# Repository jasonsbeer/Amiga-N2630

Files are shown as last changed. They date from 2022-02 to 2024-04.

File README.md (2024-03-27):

  
The N2630 is a 50MHz Motorolla MC68030 CPU card with additional RAM and ATA device port for the Amiga 2000 family of computers. It is installed in the CPU slot where it immediately upgrades the system to the MC68030 processor with FPU, up to 264 megabytes of Fast RAM, and an ATA port. The N2630 is intended to be an evolution of the A2630 card.  

<br />Look for the N2630 channel on Discord: https://discord.gg/NU7SPYfNFj  

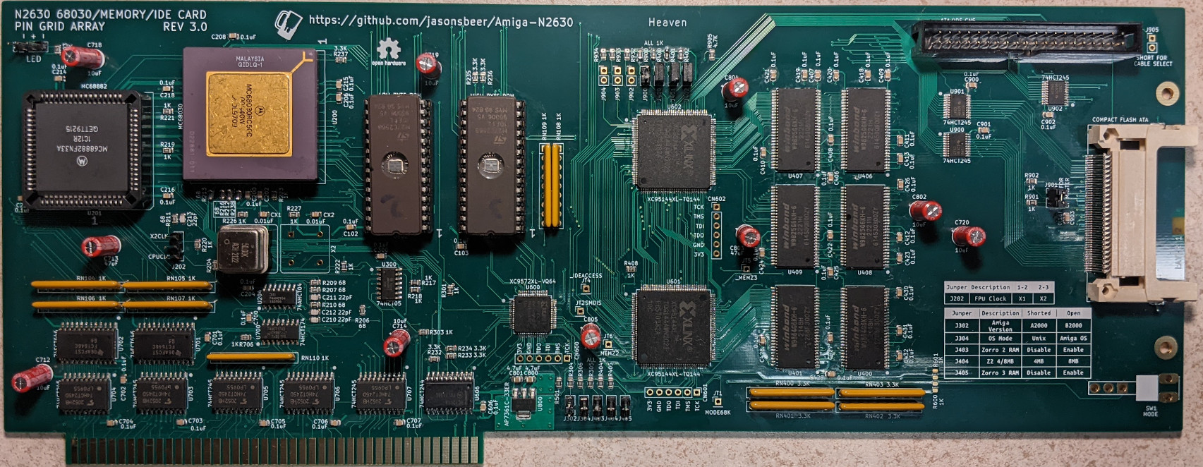
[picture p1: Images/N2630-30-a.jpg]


## CURRENT STATUS:
**Revision 4.1.0a/b is the current production release.**  

Sub-revision "a" supports the PLCC footprint MC68882. Sub-revision "b" supports the PGA footprint MC68882. They are otherwise identical.  

See the [issues](https://github.com/jasonsbeer/Amiga-N2630/issues) tab for known issues. [Click here](/TestedDevices.md) to see a list of devices tested with the N2630.

<p align="center">
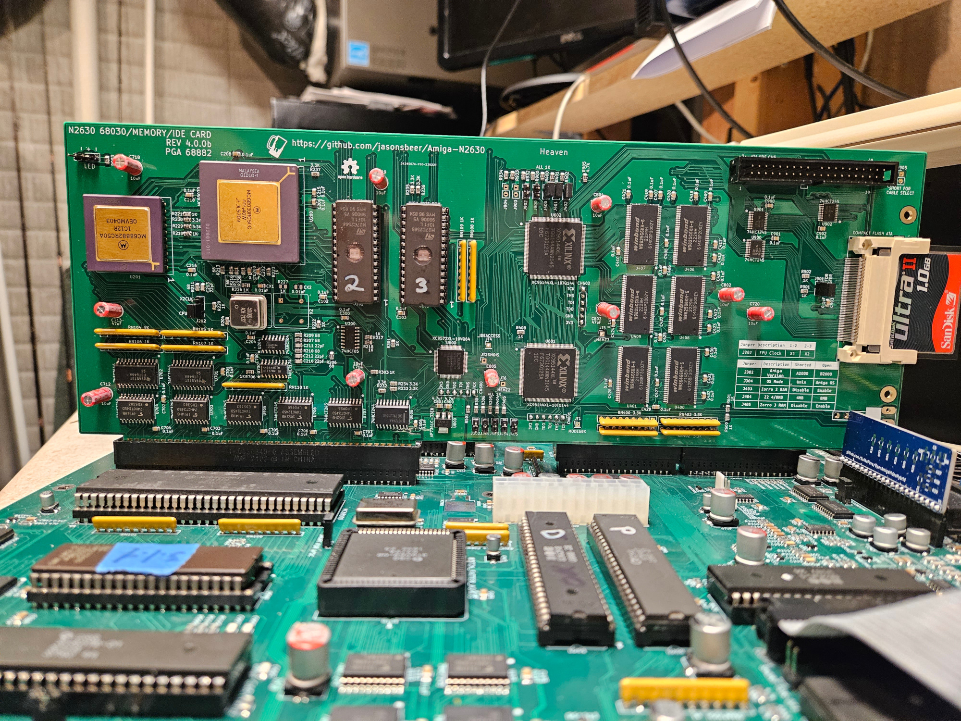
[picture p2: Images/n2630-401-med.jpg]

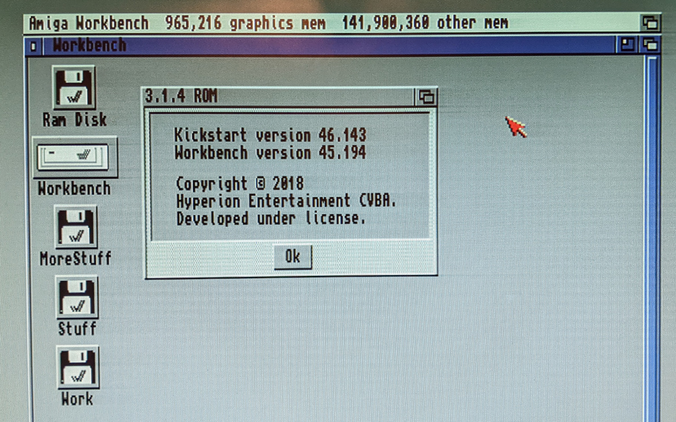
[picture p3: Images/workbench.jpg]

</p>

## Features
1. Motorola 68030 microprocessor running at 50MHz.
2. Motorola 68882 math coprocessor running up to 50MHz.
3. 4 or 8 megabytes of Zorro 2 Fast RAM.
4. 16 to 256 megabytes of Zorro 3 Fast RAM.
5. ATA port with 40-pin cable and compact flash card options.

## Assembly Notes
Click [here](/AssemblyNotes.md) for more information on building the N2630.

## Installation Notes
This card may be installed in any Amiga 2000 computer. Installation is simply inserting the card into the 86 pin CPU/Coprocessor slot of the Amiga computer. There are no software drivers to install.  Kickstart v37.300 and greater is recommended.

**IMPORTANT:** Before installing a Revision 4.x.x or greater N2630, it is necessary to determine if you have an early, non-cost reduced motherboard. If your motherboard is marked "Made In Germany" and "(C) 1986 Commodore" on the left side of the board, you have a non-cost reduced Amiga 2000 board, designated "A2000" in this documentation. An example of a non-cost reduced Amiga 2000 motherboard can be see [here](http://amiga.resource.cx/photos/a2000,1). In the event you have an non-cost reduced "A2000" motherboard, you must remove the Motorola 68000 processor from the Amiga 2000 motherboard and place a jumper at J302 of the N2630.  All other Amiga 2000 motherboards are designated "B2000" and should leave the Motorola 68000 in place. Revision 3.0.x cards do not support the original German A2000. 

**NOTES:**  
**1) Hardware revision 4.x.x supports the original Germal A2000, but is untested.**  
**2) The A2091 hard drive card will not operate correctly when using Kickstart 1.x on a revision 6.2 or newer Amiga 2000 with the N2630 or A2630 CPU cards. You must use Kickstart 2.04 or newer.**

## 68030 Mode
By default, the N2630 starts in 68030 mode. When in 68030 mode, all installed RAM and the ATA device port are active.

## 68000 Mode
When desired, the 68030 may be disabled during a cold or warm start. This results in the Amiga falling back to the 68000 processor. This may be desired when software does not run correctly on the 68030 processor. To start up in 68000 mode, hold down the right mouse button during startup. Select "68000" and the Amiga will reset with the 68000 as the active processor. When in 68000 mode, the ATA port and on-board RAM are inactive. Motorola 68000 mode is not available with A2000 motherboards.

## 68882 Math Coprocessor (FPU)
The Motorolla MC68882 (or MC68881) floating point unit may be optionally added to the N2630. The FPU is typically driven at the same clock frequency as the MC68030 via the X1 oscillator, but may be clocked independently via the X2 oscillator (see Table 3, J202).

## ROMs
The N2630 requires two 27C256 EPROMs (burned by the user) to function. The ROMs handle the system startup for CPU selection and contains the [LIDE.device](https://github.com/LIV2/lide.device) AUTOBOOT ROM. See the instructions [here](/ROMs.md) for burning the N2630 ROMs.

## FAST RAM
The N2630 uses SDRAM to provide the necessary memory for the Amiga system. SDRAM is the successor to Fast Page Memory found in devices such as the Amiga 3000, A2630 processor card, and other computers of the time. SDRAMs are a cost effective way to supply memory to older systems and are readily available either new or from unused memory modules. 

### Zorro 2
Zorro 2 RAM is the Amiga RAM found in the 24 bit address space of the Motorola MC68000 processor. The Zorro 2 RAM on the N2630 is accessed by the 68030 as a 32-bit data bus and supports 16-bit DMA activities of the Zorro 2 bus. Placing a jumper at position J404 will limit the amount of RAM to 4MB in the Zorro 2 space, allowing 4MB of address space to be made available to other Zorro 2 devices. As an example, if you have a 4MB Zorro 2 video card, it will be necessary to set jumper J404 to free up this address space for the video card. Failure to do so will result in the video card failing to pass the AUTOCONFIG process. As another example, if you have two 4MB Zorro 2 devices, such as a video card and Bridge card, these devices require the entire 8MB Zorro 2 address space. In this situation, you must disable the Zorro 2 RAM entirely by placing a jumper at J403.

Using expansion memory on the Zorro 2 bus is not recommended, as this will negatively impact the performance of the MC68030 when accessing this memory on the Zorro 2 bus. The expansion memory on the N2630 should always be used as a first choice.

NOTE: Any SDRAM at least 2Mx16 in capacity in the 54-TSOP II footprint may be placed. However, it is not possible to achieve more than 8 megabytes of Zorro 2 RAM capacity. 

### Zorro 3
Zorro 3 RAM is the Amiga RAM found in the 32-bit address space of the Motorola MC68030 processor. The Zorro 3 RAM on the N2630 supports the cache burst mode of the 68030 processor. Both Zorro 2 and Zorro 3 RAM are used together on the N2630 card. Thus, the total memory available to the system will be the sum of the Zorro 2 and Zorro 3 RAM. 

Zorro 3 SDRAMs may be installed in different configurations to achieve a specific amount of final RAM (Table 1a). SDRAM must be installed in pairs, or banks, to achieve the needed 32 bit data path. Positions U406 and U407 represent the "low" bank and positions U408 and U409 represent the "high" bank. The banks must be populated as the low bank only or both low and high banks. The high bank will not function without the low bank populated. The SDRAM footprint is 54-TSOP II. The indicated jumpers must be set as shown or your system may not function correctly. When installing both banks, jumpers J400 and J401 must be set as shown in tables 1b and 1c. If only the low bank is populated, these jumpers are not used.

The Zorro 3 memory supports AUTOCONFIG with Kickstart 2.04 and newer and will be auto sized by Amiga OS. When using Kickstart version 1.x, place a jumper at J405 to disable the Zorro 3 AUTOCONFIG. An addmem style program may be used to add the Zorro 3 memory to the Amiga's memory pool. See Table 1d for the N2630 Zorro 3 memory map.

**Table 1a.** Possible Zorro 3 RAM Combinations for the N2630.
Desired Zorro</br>3 RAM (MB)|SDRAM|Low Bank</br>(U406 and U407)|High Bank</br>(U408 and U409)
-|-|-|-
16|4MX16|Populated<sup>A</sup>|Unpopulated<sup>B</sup>
32|4MX16|Populated|Populated
32|8MX16|Populated|Unpopulated
64|8MX16|Populated|Populated
64|16MX16|Populated|Unpopulated
128|16Mx16|Populated|Populated
128|32MX16|Populated|Unpopulated
256|32MX16|Populated|Populated

<sup>A</sup>These SDRAM positions are populated by the SDRAM indicated.  
<sup>B</sup>This SDRAM positions are not populated.

**Table 1b.** SDRAM Bank Jumper Setting.
Zorro 3 RAM</br>Banks Populated|J400
-|-
Low Bank Only|Open<sup>A</sup>
Both Banks|Shorted<sup>B</sup>

<sup>A</sup>No jumper.  
<sup>B</sup>Jumper placed. 
  
**Table 1c.** Jumper Configurations When Both Low and High Memory Banks Are Populated.
Desired Zorro</br>3 RAM (MB)|SDRAM</br>Capacity|J401<sup>[A]</sup>|J402<sup>[A]</sup>
-|-|-|-
32|4MX16|Open<sup>[B]</sup>|Shorted<sup>[C]</sup>
64|8MX16|Shorted|Open
128|16Mx16|Shorted|Shorted
256|32MX16|Open|Open

<sup>A</sup>Ignored when J400 is open.  
<sup>B</sup>No jumper.  
<sup>C</sup>Jumper placed.  

**Table 1d.** N2630 Zorro 3 Memory Map.
Desired Zorro</br>3 RAM (MB)|Starting Address|Ending Address
-|-|-
16|$40000000|$40FFFFFF
32|$40000000|$41FFFFFF
64|$40000000|$43FFFFFF
128|$40000000|$47FFFFFF
256|$40000000|$4FFFFFFF

## ATA Port
The N2630 includes a buffered, host terminated AUTOBOOT ATA port for hard drives and ATAPI devices. The N2630 implements [LIDE.device](https://github.com/LIV2/lide.device) as the ATA driver. The driver must be present on the N2630 ROMs for the ATA port to function. See [ROMs](#roms) for more details. The ATA port may be accessed via the 40-pin ATA header and the compact flash card slot. There are a few different ways to combine devices on the port, but the total number of ATA devices on the N2630 cannot exceed two (master and slave). For instructions on installing a new hard drive on Amiga computers, refer to the [Commodore Hard Drive User's Guide](DataSheet/Hard_Drive_Users_Guide.pdf). This includes the HDToolBox user guide and other useful information for setting up both ATA and SCSI devices. 

The ATA logic supports four speed modes: PIO0, PIO2, PIO4, and SanDisk Ultra 2 (see Table 2B). The modes PIO0, PIO2, and PIO4 follow the published timing specifications of those modes, with PIO0 being the slowest. The SanDisk Ultra 2 mode was developed for the SanDisk Ultra 2 compact flash card and is capable of 7.4M/s transfer rate. The SanDisk Ultra 2 mode is an undocumented ATA timing and may or may not work with other devices. The speed mode you select will be determined by the slowest ATA device on your system. To determine what speed your devices support, it is recommended to start with the slowest setting (PIO0) and adjust one setting faster until one of your devices stops working. The mode you choose should be the fastest mode where all devices function correctly. Jumpers should only be changed while the system is off.

Each ATA device must be set as slave or master. Devices present on the 40 pin ATA port may use cable select by shorting J905 when using a proper cable select ATA cable. See the manual for each device on how to designate the device's master or slave setting. Master and slave for the compact flash device are set via J901 on the N2630.

**NOTE:** The compact flash card slot is not affected by the cable select jumper (J905).  Thus, J905 should only be used when a proper cable select ATA cable is implemented on the 40 pin ATA port.

**Table 2A.** ATA Configuration Jumper Settings.
Jumper|Description|Open<sup>[A]</sup>|Shorted<sup>[B]</sup>
-|-|-|-
J900|RESERVED||
J901|Compact Flash Select|Slave|Master
J902|PIO MODE||
J903|PIO MODE||
J904|RESERVED||
J905|Cable Select|Disable|Enable

<sup>A</sup>No jumper.  
<sup>B</sup>Jumper placed. 

**Table 2B.** ATA PIO Mode.
Mode|J902|J903
-|-|-
PIO0|Shorted<sup>[A]</sup>|Shorted|
PIO2|Shorted|Open<sup>[B]</sup>|
PIO4|Open|Shorted|
SanDisk Ultra 2|Open|Open|

<sup>A</sup>Jumper placed.  
<sup>B</sup>No jumper.  

## Other Jumper Settings
In the following tables, OPEN indicates no jumper. Shorted indicates the presence of a jumper on the pins indicated. All jumpers must be set correctly or you may encounter unexpected behaviors or failure to boot.

**Table 3a.** Configuration Jumper Settings
Jumper|Description|Shorted|Open<sup>[A]</sup>
-|-|-|-
J302|Amiga Version|A2000|B2000
J304|OS Mode|Unix|Amiga OS
J403|Zorro 2 RAM|Disable|Enable
J404|Z2 4/8MB|4MB|8MB
J405|Zorro 3 RAM|Disable|Enable

<sup>A</sup>The factory configuration for all jumpers is open (no jumper).  

**Table 3b.** System Clock Jumper Settings
Jumper|Description|1-2|2-3
-|-|-|-
J202|FPU Clock|X1<sup>[A]</sup>|X2<sup>[B]</sup>

<sup>A</sup>FPU clock from X1. Factory default.  
<sup>B</sup>FPU clock from X2.

## Revision History
<strong>Revision 4.1.0a/b</strong>  
   Added ATA activity light buffer to address config issues with some ATA devices.  
   Changed polarity of the ATA LED header.  
   
<strong>Revision 4.0.1a/b</strong>  
   Sub-revision 'a' supports PLCC MC68882, sub-revision 'b' supports the PGA MC68882.  
   Changed jumper footprint to increase ease of assembly.  
   Added order number location for JLCPCB.  
   Added support for original German A2000 machines.
   
<strong>Revision 3.0.1</strong>  
   Added copper thieving areas to top and bottom layers.  
   
<strong>Revision 3.0</strong>  
   Initial production release.  

## Acknowledgements
Dave Haynie for sharing the A2630 technical details with the Amiga community.  
Matt Harlum (LIV2) for sharing his Gayle ATA code, LIDE.device, submitting code improvements, listening my struggles, and his numerous other contributions to this project.  
Stephen Durham (steveed) for loaning me his ethernet cards.  
Members of the Discord testing group: LIV2, steeveed, Chrissy, Pillock.  
Everyone who made the Amiga possible.  

Last Updated: March 26, 2024

## License
<br />This work is licensed under a <a rel="license" href="http://creativecommons.org/licenses/by-nc-sa/4.0/">Creative Commons Attribution-NonCommercial-ShareAlike 4.0 International License</a>.

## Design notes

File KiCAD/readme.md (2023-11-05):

These are KiCAD files for the N2630.  

There are two versions of the N2630 card. One for the PLCC footprint MC68882 coprocessor and one for the PGA footprint MC68882 coprocessor. The two sub-revisions are otherwise identical.

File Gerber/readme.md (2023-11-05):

These are Gerber files for the Rev 4.0.1 N2630.  

There are two versions of the N2630 card. One for the PLCC footprint MC68882 coprocessor and one for the PGA footprint MC68882 coprocessor. The two sub-revisions are otherwise identical. Choose the one that best meets your needs.

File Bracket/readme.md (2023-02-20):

These are mounting brackets for the N2630. All files are included to 3D print or edit the brackets. There is one for the Commodore Amiga 2000 and one for the A2000 EATX.

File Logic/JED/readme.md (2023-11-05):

These are the current production JED files for programming the Xilinx CPLDs.

The U600 "SE" logic replaces the E clock CIA timing in favor of timings from the 8520A datasheet. This is the preferred logic for most applications. If you have a Zorro 2 device that relies on E clock timings, you should use the non-SE logic version for U600.

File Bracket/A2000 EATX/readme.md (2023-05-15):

Mounting bracket for the N2630 and Amiga 2000 EATX computer. Designed to use M3x5 or similar sized screws. STL and FreeCAD files are included.

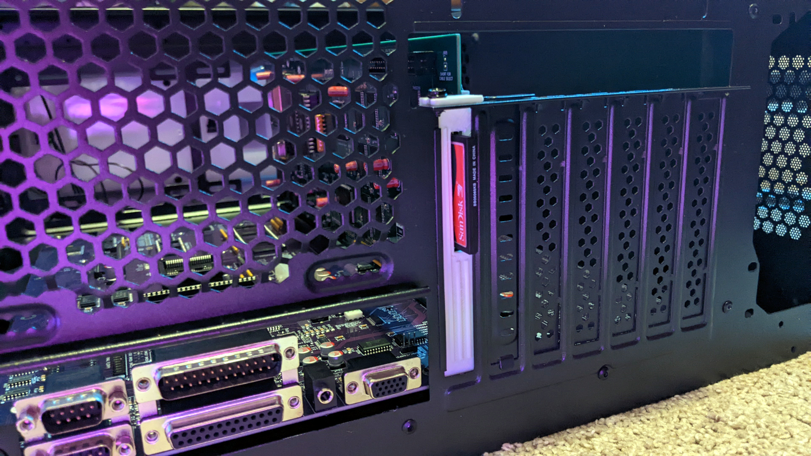
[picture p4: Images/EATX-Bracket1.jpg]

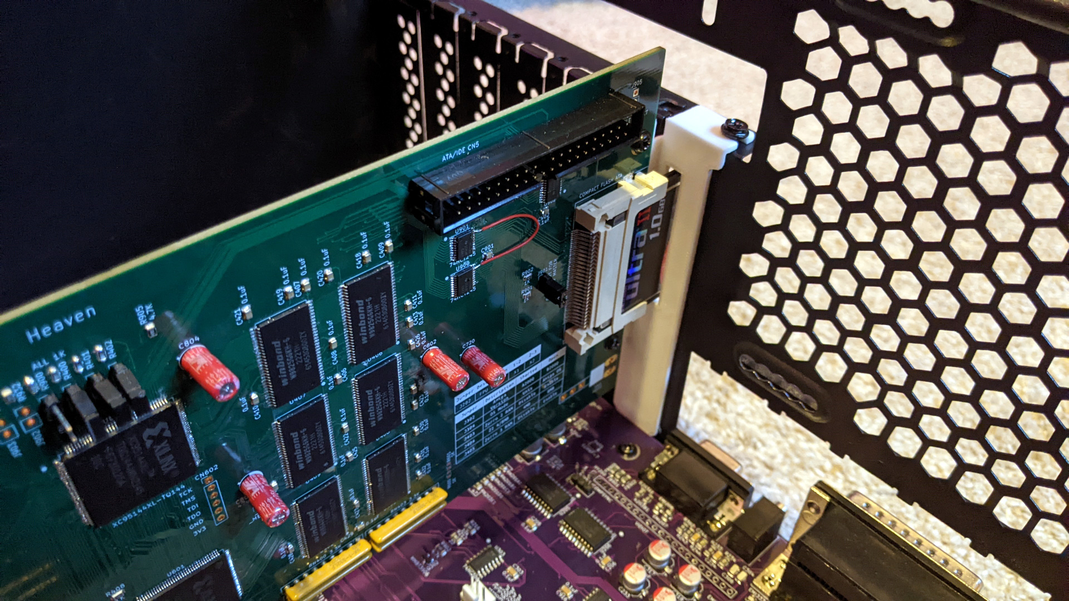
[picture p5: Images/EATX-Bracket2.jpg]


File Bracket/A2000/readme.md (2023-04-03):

Mounting bracket for the N2630 and Commodore Amiga 2000 computer. Designed to use M3x5 or similar sized screws. STL and FreeCAD files are included.

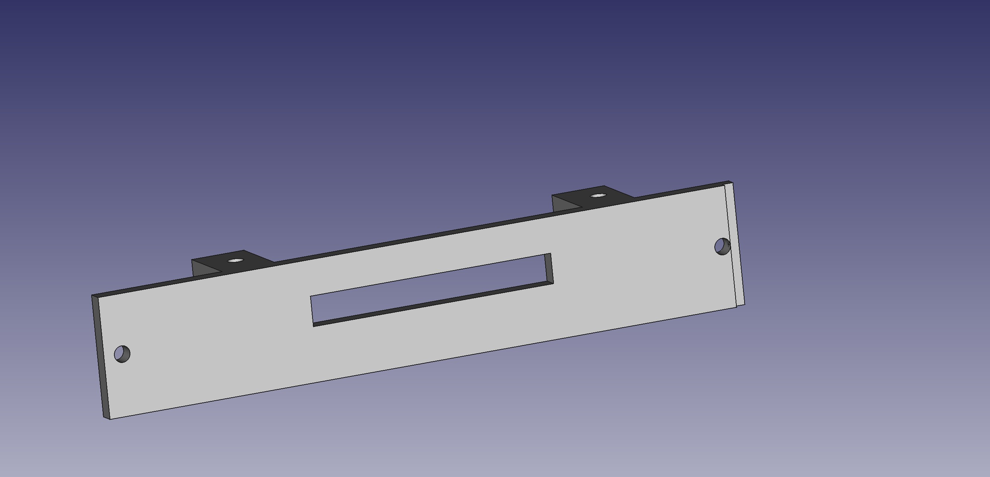
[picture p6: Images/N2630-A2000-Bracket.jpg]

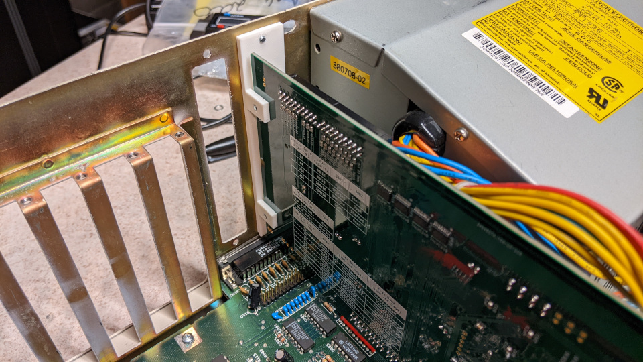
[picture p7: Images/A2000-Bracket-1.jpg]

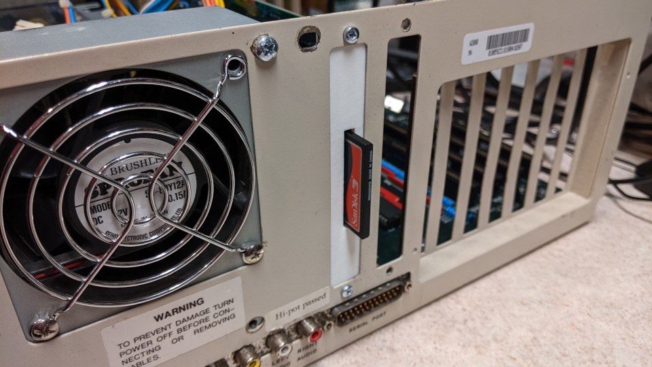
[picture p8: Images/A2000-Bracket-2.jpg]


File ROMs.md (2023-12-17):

# Building the N2630 ROMs

The N2630 requires two 27C256 EPROMS with the correct ROM images to function. The low ROM occupies space U102 and the high ROM occupies U103.

## BIN Files
Before burning, you must acquire the following files:

[A2630 High ROM](/ROM)  
[A2630 Low ROM](/ROM)  
[LIDE.device High ROM](https://github.com/LIV2/lide.device/releases/latest/download/lide-N2630-high.rom)  
[LIDE.device Low ROM](https://github.com/LIV2/lide.device/releases/latest/download/lide-N2630-low.rom)  

## Burning
You must combine the two HIGH ROM and two LOW ROM files together before burning. Instructions are given here to combine the ROM files with the XGecu Pro software for the TL866II (and successor) programmers. Other programmers should have similar functionality, but are outside the scope of this document.

The A2630 ROM occupies $0000 - $3FFF of each EPROM. The LIDE.device occupies $4000 - $7FFF of each EPROM.  

From the XGecu software:  

1. Import the A2630 Low ROM: Use the default import settings. After importing, you should see data in the $0000 - $3FFF address range. The bytes in last few lines are all $FF, which is normal.  

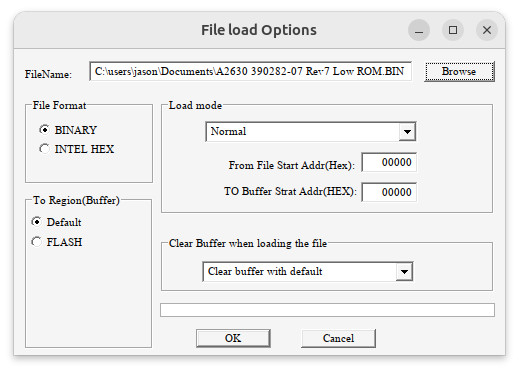
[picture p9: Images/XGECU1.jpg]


2. Import the LIDE.device Low ROM: Select the file and change the import settings as follows:  
   2a. To Buffer Strat[SIC] Addr(HEX) = 04000  
   2b. Clear Buffer When Loading the File = DISABLE.  
   2c. Click OK to import the file.

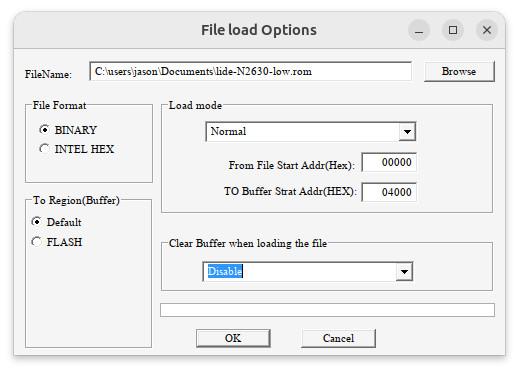
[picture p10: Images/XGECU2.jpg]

   
4. You should now see the LIDE.device data has occupied the $4000 - $7FFF address range.  
5. The A2630 data should still occupy the $0000 - $3FFF range. If not, repeat from step 1.  
6. Burn the EPROM as per programmer user manual.
7. Label the EPROM.
8. Repeat steps 1 - 6 with the HIGH ROM files.  

You should now have two ROMS, low and high, for the N2630.

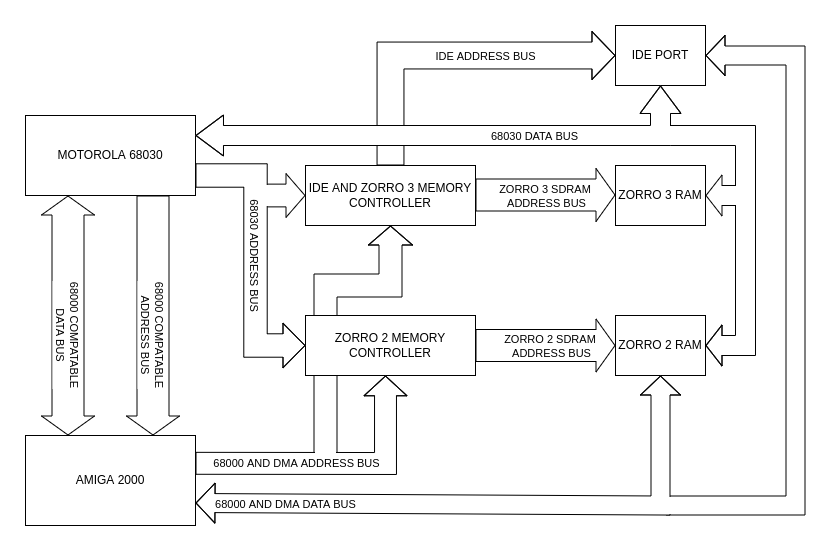
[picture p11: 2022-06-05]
Images/BD.png

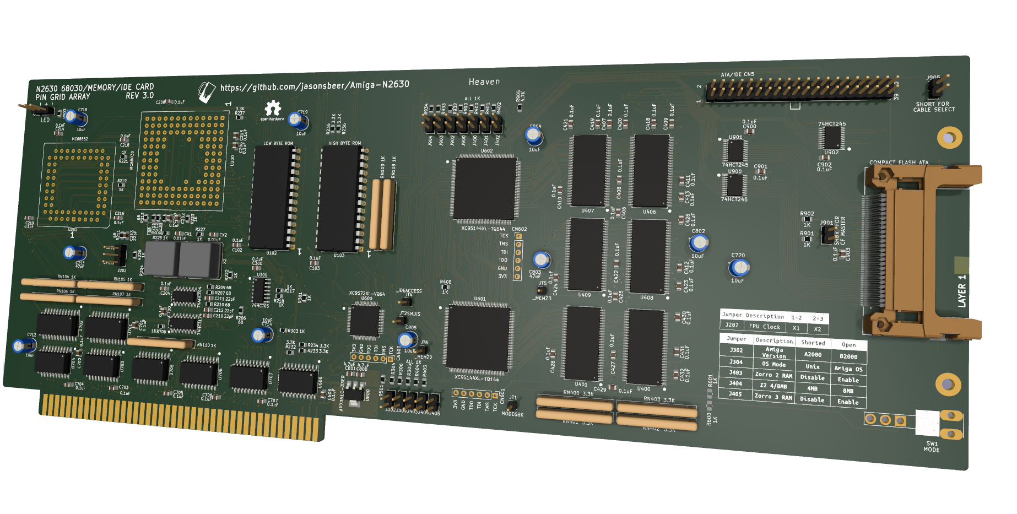
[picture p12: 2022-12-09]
Images/N2630-30med.png

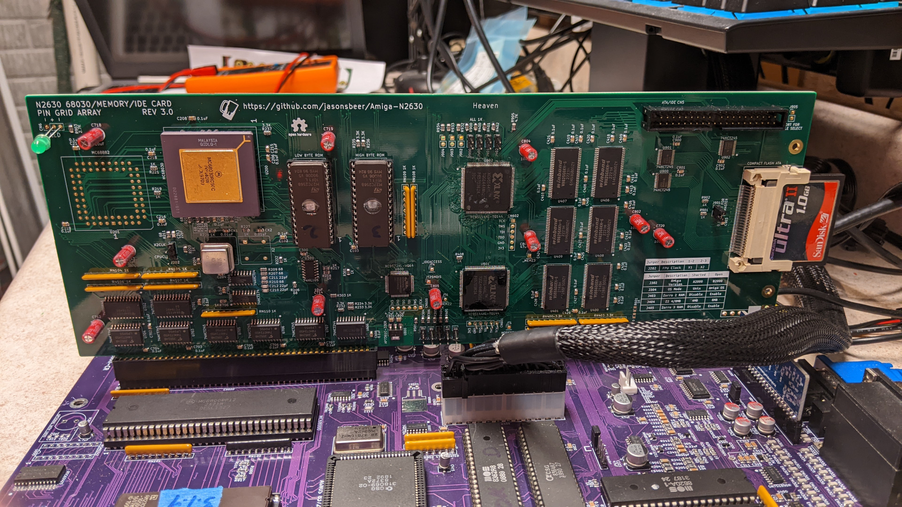
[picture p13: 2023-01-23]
Images/N2630REV30.jpg

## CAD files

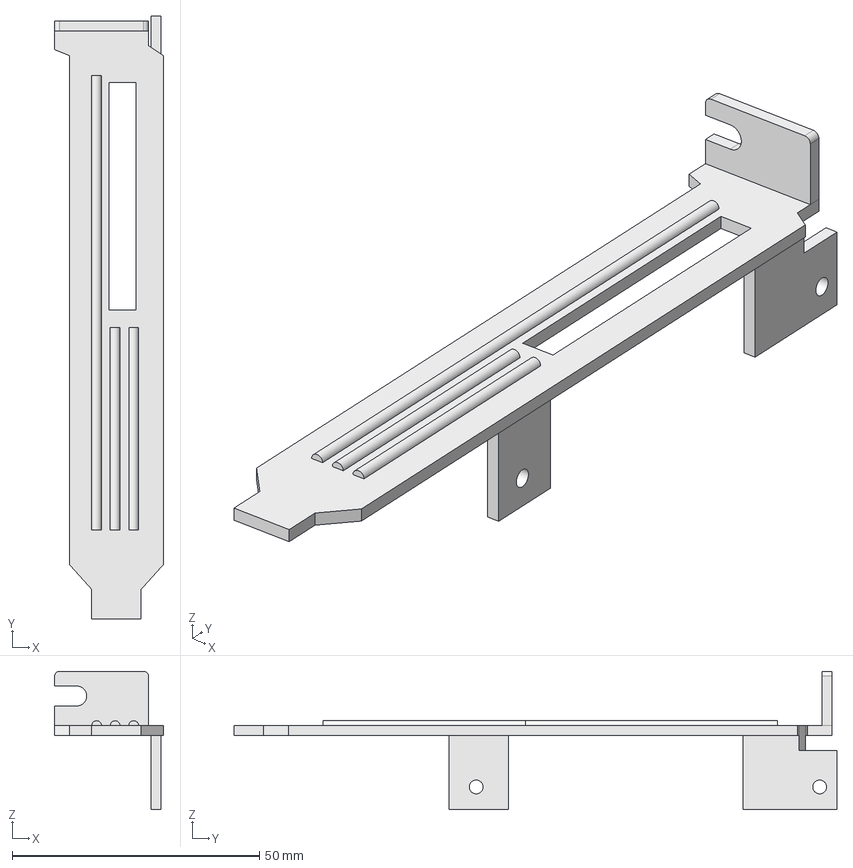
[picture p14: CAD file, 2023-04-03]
Bracket/A2000 EATX/A26x0 Slot Cover.FCStd
22.0 x 122.0 x 28.0 mm

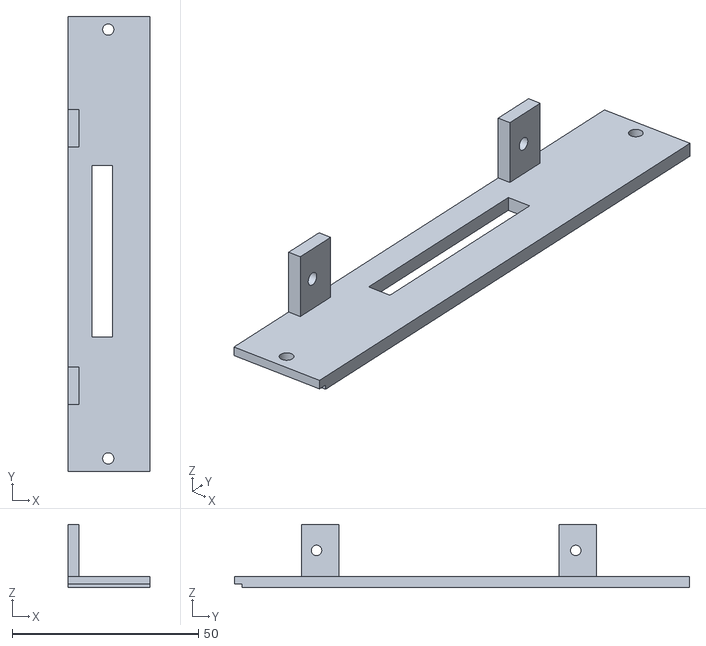
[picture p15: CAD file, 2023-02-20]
Bracket/A2000/N2630-A2000-Bracket-Body.stl
22.0 x 122.0 x 17.0

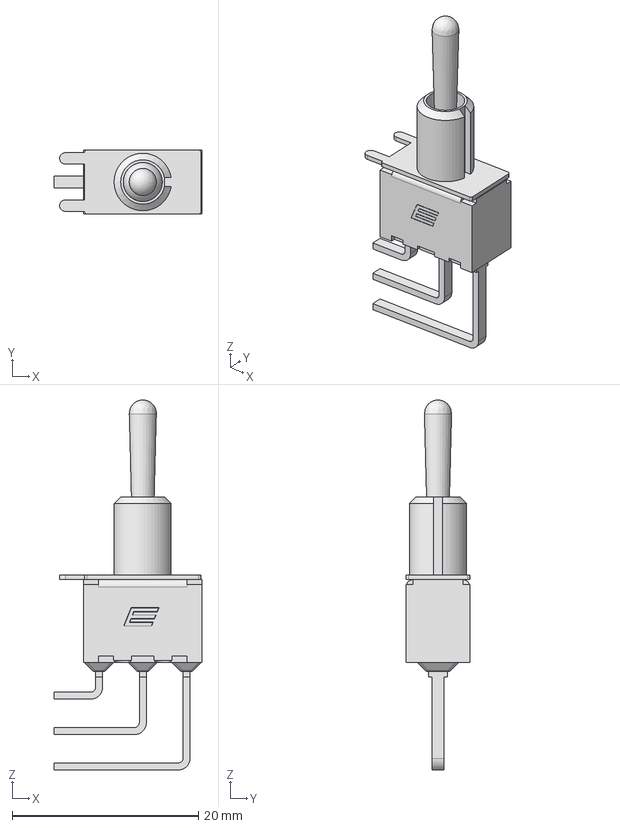
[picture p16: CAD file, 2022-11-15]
KiCAD/A2630-New-KiCAD-Rev410-PGA/N2630 Libraries/100SP1T1B1M7QE--3DModel-STEP-520916.STEP
15.9 x 6.86 x 39.8 mm

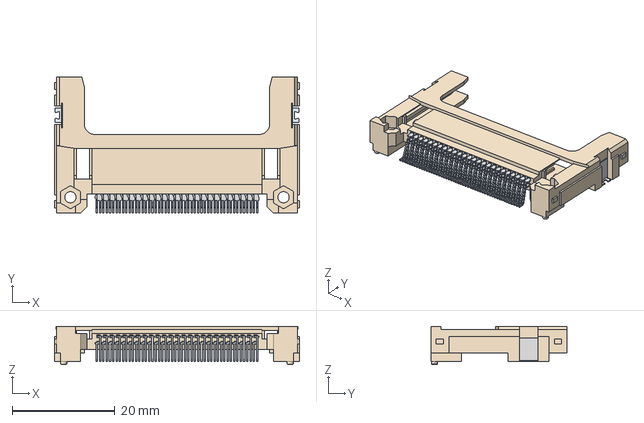
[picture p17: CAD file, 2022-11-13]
KiCAD/A2630-New-KiCAD-Rev410-PGA/N2630 Libraries/COMPACT-FLASH-SLOT.step
47.6 x 26.5 x 7.40 mm

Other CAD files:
Bracket/A2000 EATX/N2630-Slot-Cover.stl
Bracket/A2000/N2630-A2000-Bracket.FCStd

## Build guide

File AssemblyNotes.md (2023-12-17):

# Assembly Notes, BOM, and Ramblings

IMPORTANT INFORMATION. It is highly recommended you read this entire page before committing to assemble the N2630. You must also review any postings in the [Issues](https://github.com/jasonsbeer/Amiga-N2630/issues) tab to fully understand any limitations or issues.

**Disclaimer:** This project is free and open source. It is a very complex project and should only be undertaken by individuals experienced in SMD assembly techniques. It requires knowledge and tools for programming complex logic devices and EPROMs. No warranty or guarantee is offered that it will work for your particular situation. You assume all risk should you choose to build it.

## Ordering PCBs

The N2630 PCB is a full-size Amiga 2000 CPU card with 4 layers. You can find the Gerber files [here](/Gerber). The recommended order settings for JLCPCB are included below. When ordering, it is recommended you choose the ENIG surface finish and chamfer the card edge. You should define the layer stackup as part of the order, which is shown below. If you choose "specify location", the order number will be placed under the CF card socket, making it invisible once assembled. Order the solder mask color of your choice.

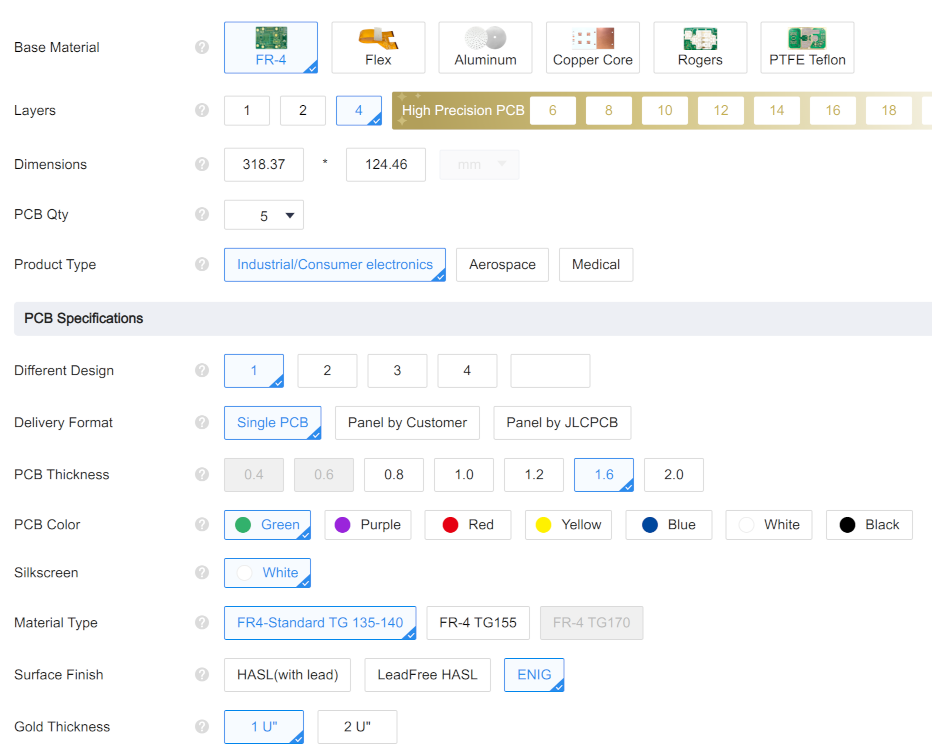
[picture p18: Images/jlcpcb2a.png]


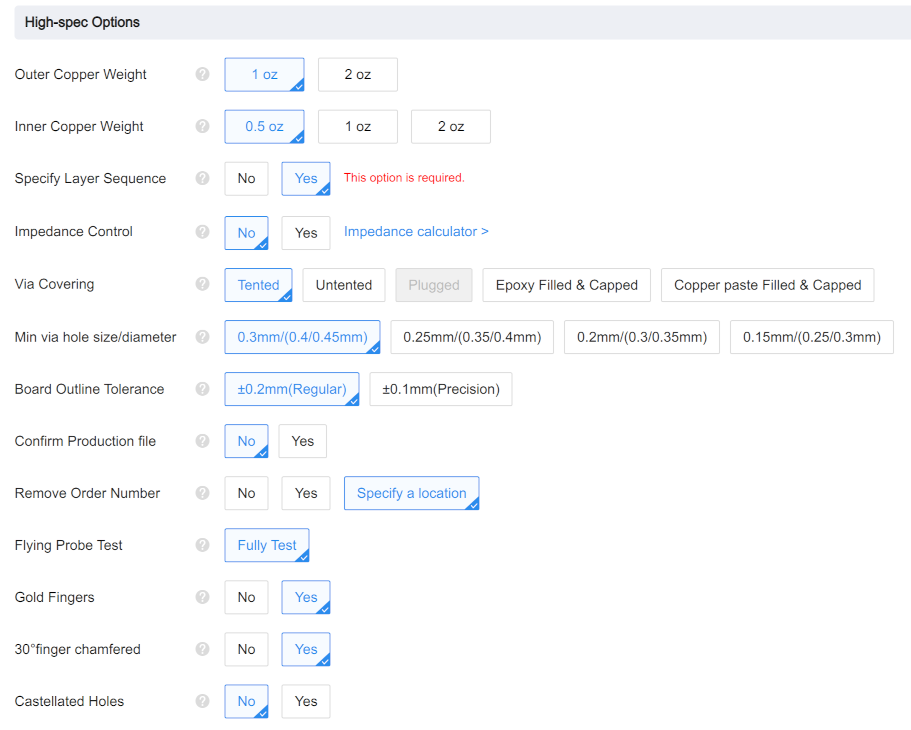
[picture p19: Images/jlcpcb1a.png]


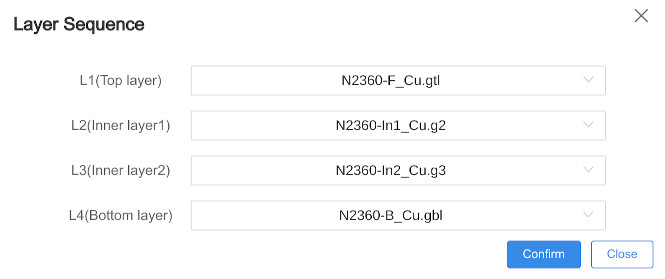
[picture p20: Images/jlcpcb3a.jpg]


## Bill of Materials  

The official IBOM is found [here](/BOM) and should be used for ordering parts. You can copy the BOM from the IBOM HTML page. The IBOM can also be used to locate components on the board. Download the file and open it your browser.

The MC68030 and MC68882 need to be obtained through a retailer that handles legacy Motorola devices. At the time of writing this, you should expect to pay US$30 - $50 each. DO NOT buy components where you get five chips for $20. These are likely counterfeit or remarked chips. Save yourself the misery and pay for the real ones.

Most compents in the BOM are general purpose passive and logic parts with many compatable alternatives. Due to availability of parts, it is difficult to keep a list of part numbers that remains valid even for a short period of time. Thus, I have not supplied a list of part numbers. When ordering, be sure the value and footprint of the part is correct, and you should be good.

**It is important to use the -10 speed rated Xilinx CPLDs in this project. The logic equations are designed for that speed. Going to faster rated CPLDs may break the timings and result in erratic behavior.**

PGA-128 sockets are very difficult to find and can be very expensive. A good alternative is to use machine pin strips to make your own socket. It is not pretty, but it works well. The Motorola parts you obtain may be pulls and have bent pins, which makes it very difficult to line up to the socket. I recommend adding the machine pin socket strips to the MC68030 one row at a time. You can then install the entire assembly for soldering. This greatly simplifies installation of the MC68030 on the board.

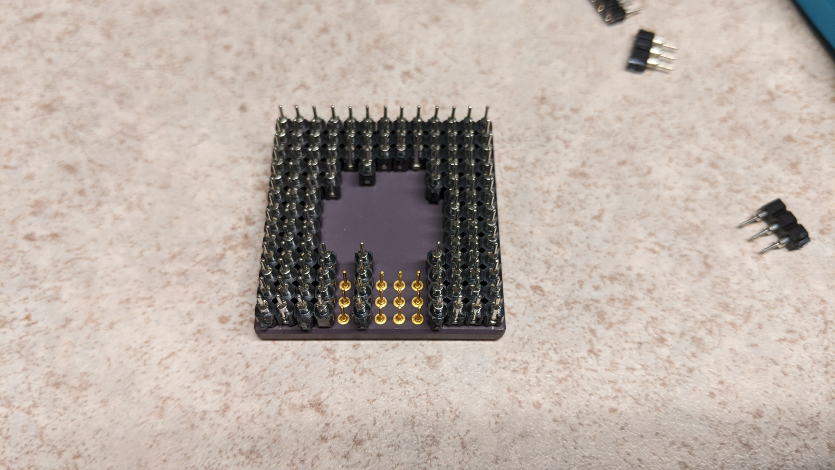
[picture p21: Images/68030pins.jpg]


**NOTE:** 

1) Be sure to select 166MHz SDRAM. Slower SDRAM may not work at 50MHz.
2) Sockets are NOT listed in the BOM. I prefer 3M sockets for my projects.
3) Components not listed on the BOM are reserved for future use and do not need to be populated.
4) I recommend you do not install the 68882 (or socket) until everything is known to work. The through holes here are very convienient for connecting probes in the event troublshooting is required.

## Programming the CPLDs
The three CPLDs (U600, U601, and U602) must be programmed before the N2630 will function. Each CPLD has a dedicated programming port, CN600, CN601, and CN602. The best way to program these is to plug the card into the Amiga, power it on, and program it while in circuit with power coming from the Amiga 2000. The JED files can be found [here](/Logic/JED). Make certain to program each CPLD with the matching JED file. 

Discussion of CPLD programming is not in the scope of this document, but many resources are available on the internet. I recommend a Xilinx (real or generic) programming dongle.

## Programming the ROMs
Most cheap EPROM programmers will handle the 27C256 EPROMs of the N2630. A popular one is the TL866II, but there are other options. There are a lot of these in the community. Someone may be able to assist if you do not wish to purchase a programmer. The EPROMs are programmed independently of the N2630. Instructions for programming the ROMs can be found [here](/ROMs.md).

## Mounting Brackets
There are mounting brackets for the Amiga A2000 EATX and Commodore Amiga 2000. The bracket matching your setup can be 3D printed and used for a clean installation. The files are found [here](/Bracket).

## Troubleshooting
1) Make sure you have the newest firmware logic installed.
2) Check for solder bridges or bad solder joints.
4) Double check the jumpers. It is critical the jumpers be set correctly for proper and reliable function.
5) Disable the Zorro 2 RAM, Zorro 3 RAM, and the IDE port. The Amiga 2000 will boot without these and it may help narrow down where the issue lies.

Follow these troubleshooting order of operations if your Amiga 2000 fails to start in 68030 mode or starts to a black screen. If these steps are executing correctly, you should start in 68030 mode and see the Kickstart screen. There a test points that can be used to help in troubleshooting process.

Table 1. N2630 startup order of operations.
Step|Expected Function|Possible Failure
-|-|-
1|N2630 asserts bus request (_BR at MC68000)|Bad solder joint. No power to U600.
2|MC68000 asserts bus grant (_BG)|
3|N2630 asserts _BOSS (_BGACK at MC68000) and negates bus request (_BR)|Bad solder joint. No power to U600.
4|MC68000 negates bus grant (_BG)|
5a|N2630 _CSROM begins oscillating|Bad solder joint on A(23..16) or _CSROM to U601. No power to U601.
5b|Concurrent with 5a, SMDIS begins oscillating|Bad solder joint at U600 or U601. No power to U601.
5c|Concurrent with 5a and 5b, N2630 drives MC68000/A2000 data and address buses to read A2000 chip registers|Bad solder joint or no power at U701, U702, U703, U704, U705, U706, U707. Bad solder joint signals _AAENA, AADIR, DRSEL, _ADOEH, _ADOEL, ADDIR, _AAS, _LDS, _UDS, AR_W, etc...
6|N2630 negates _CSROM|Bad solder joints on A(15..1) or D(31..16) at U102, U103, or MC68030.
7|N2630 drives MC68000/A2000 data and address buses|Bad solder joint or no power at U701, U702, U703, U704, U705, U706, U707. Bad solder joint signals _AAENA, AADIR, DRSEL, _ADOEH, _ADOEL, ADDIR, _AAS, _LDS, _UDS, AR_W, etc...
8|Kickstart screen appears|

Table 2. N2630 test points.
Test Point|Meaning|Purpose
-|-|-
SMDIS|State Machine Disable|This signal is HIGH when onboard ROM, RAM, or IDE address spaces are active.
_MEMZ2|Zorro 2 Memory Access|This signal is LOW when onboard Zorro 2 RAM address space is active.
_MEMZ3|Zorro 3 Memory Access|This signal is LOW when onboard Zorro 3 RAM address space is active.
_IDEACCESS|IDE Access|This signal is LOW when onboard IDE address space is active.
MODE68K|68000 Mode|This signal is HIGH when the N2630 is operating in Motorola 68000 mode. Low when in Motorola 68030 mode.

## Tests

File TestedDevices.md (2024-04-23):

The purpose of this list is to catalog devices that have been tested and are known to work with the N2630. To report additional devices (working or not working), open a new issue in the repository. 

<ins>Amiga</ins>  
A2000 Rev 4.x (non-modified)  
A2000 Rev 6.x  
A2000 EATX  

<ins>Bridge Cards</ins>  
A2088  
A2286  

<ins>Hard Drive Controllers</ins>  
A2091  
RIPPLE  
Oktagon SCSI  
WordSync  

<ins>Memory</ins>  
GottaGoFastRam  
ACE2b  

<ins>USB</ins>  
Freeway Pro  

<ins>Ethernet</ins>  
XSurf 100  
Ariadne  
Plipbox  

<ins>Video</ins>  
GBAPII+  
Opal Vision  
Picasso  

<ins>Sound</ins>  
Prelude

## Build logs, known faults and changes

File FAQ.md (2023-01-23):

# FAQs

### I already have a Zorro 2 memory card. Do I have to install Zorro 2 memory?
The N2630 must have on-board memory to maximize performance of the Motorolla 68030 processor. All on board memory, even in the Zorro 2 space, is 32 bits wide. In practice, you *could* omit the Zorro 2 memory if you install Zorro 3 memory. However, Zorro 2 RAM on Zorro 2 cards will be 16 bits wide accessed at 7MHz, severely restricting the MC68030 during memory access to those spaces. Alternatively, you may place a jumper at J405 to limit the N2630 Zorro 2 RAM to 4MB. This will leave 4MB of AUTOCONFIG space available for memory on Zorro 2 cards.

### My software, [fill in then blank], does not work with the N2630.
It is likely, especially for games, that some will fail when running in 68030 mode. To regain compatability, you should start your Amiga in 68000 mode. See [68000 mode](/README.md#68000-mode) on the main page.

### What are the AUTOCONFIG details?
The N2630 identifies as two seperate AUTOCONFIG devices: a Zorro 2 memory card and a Zorro 3 memory card. The manufacturer ID is listed as "600" with the Zorro 2 device as product number 0 and the Zorro 3 device as product 1. Both reflect 2630 as the serial number.
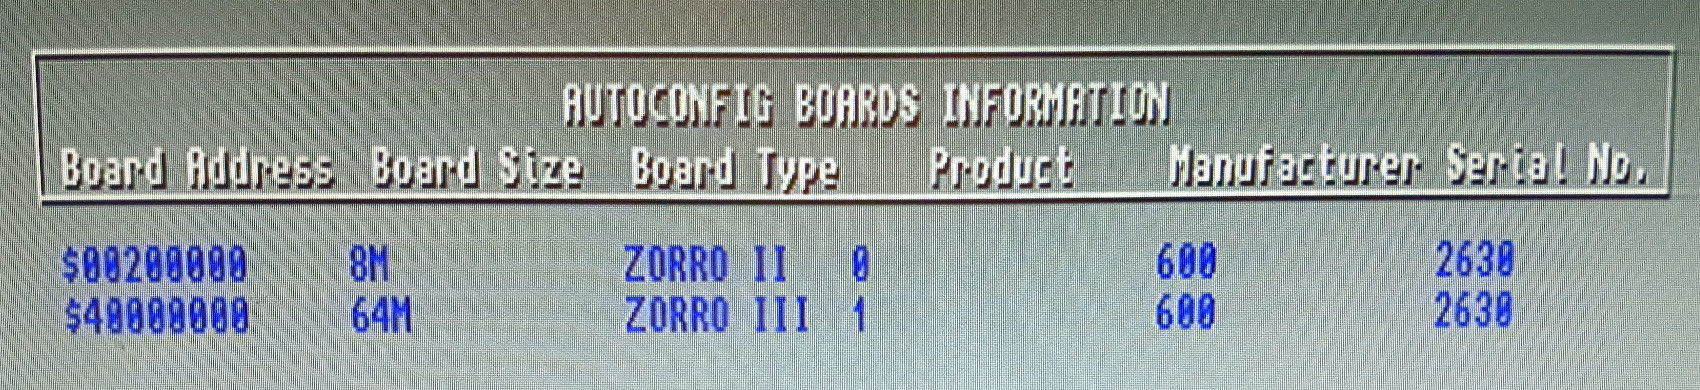
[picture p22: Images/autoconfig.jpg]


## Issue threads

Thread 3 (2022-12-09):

FPU Test

jasonsbeer, 2022-12-09:
Check functionality of MC68882 FPU. Investigate if any issues are found.

jasonsbeer, 2022-12-18:
The FPU was not being detecting by the 68030, although it was looking for it. Some observations in the oscilloscope suggested another device was not relinquishing the data bus during CPU cycles. Investigation found that the chip select logic for U701 and U702 was asserting during CPU cycles. The logic has been corrected to negate during CPU cycles. The 68030 now detects the 68882. The 68882 is now working as expected.

Closed 2022-12-18.

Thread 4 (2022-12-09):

Test DMA

jasonsbeer, 2022-12-09:
Test DMA using the N2630 Zorro 2 RAM and the A2091 SCSI card or other devices, if available. Test methodology needs to be determined. Zorro 3 RAM is not in scope.

jasonsbeer, 2023-02-03:
DMA is currently bugged. My test with the A2091 caused a Guru error. Likely there is a timing or addressing issue when accessing the SDRAM.

jasonsbeer, 2023-02-14:
DMA timings are fixed and confirmed working with the A2091 hard drive controller using Kickstart versions 2.04 and 3.1.4.

NOTE: THE FOLLOWING COMBINATION OF HARDWARE DOES NOT WORK AND WAS CONFIRMED BY COMMODORE INTERNAL MESSAGES:

Kickstart 1.x
A2000 Revision 6.2+ (including the A2000 EATX)
A2091
A2630 (or N2630)

If you use this combination of hardware, DMA is likely to fail and prevent the A2091 from functioning. This apparently is a design issue with the "pull down data bus" of these A2000 revisions. Commodore must have fixed this issue starting in Kickstart 2.04.

Closed 2023-02-14.

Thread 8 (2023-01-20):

Create Mounting Bracket

jasonsbeer, 2023-01-20:
To do: Design mounting brackets that can be 3D printed for A2000 and A2000 EATX boards.

jasonsbeer, 2023-08-22:
These mounting brackets have been completed and are in the repository.

Closed 2023-08-22.

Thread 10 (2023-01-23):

Create sub-revision supporting PGA 68882

jasonsbeer, 2023-01-23:
Current revision routing supports the PLCC 68882. Create a sub-revision that supports mounting of the PGA 68882.

jasonsbeer, 2023-11-05:
Revision 4.0.1b supports the PGA MC68882.

Closed 2023-11-05.

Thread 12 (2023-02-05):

Original German A2000 & SDRAM Refresh

jasonsbeer, 2023-02-05:
**Description:** SDRAM will not refresh with the original German A2000.

**Severity:** Low? I am not sure how many of the original German made A2000's are in the wild and how many of those few will want to use the N2630. Cost reduced versions (B2000) are not affected.

**Observations/Useful Info:** U601 and U602 consume the 7MHz clock to drive the SDRAM refresh timer. The original German A2000 does not supply the 7MHz clock at the coprocessor slot, making it unavailable to the N2630 for this purpose.

**Proposal:** Modify U601 and U602 to consume the 50MHz clock to support the original German A2000.

jasonsbeer, 2023-02-14:
Upon further consideration, this will require a hardware revision to implement. U601 needs the 7MHz clock to adhear to DMA timing. This clock will be missing on original A2000 machines. It should be possible to bodge this on current Rev 3.x boards. U600 will need a pin assignment update to implement.

TheBajaGuy, 2023-04-03:
Maybe this will help: You need an XOR of C1 and C3 clocks off the motherboard slot to create your board's 7M clock on all systems.

It's probably the safer 7M 'clock' to work with, as 7M off the machine slot can sometimes be messy from other system loads.

jasonsbeer, 2023-10-02:
I looked at recreating the 7MHz system clock from the C1 and C3 clocks. The A500/A2000 Technical Reference recommends the equation "C1 XNOR C3" (pp. 89). XOR would result in the inverse of the 7MHz clock.

Unfortunately, this results in a delay of approximately 30ns between the recreated clock and the original A2000 7MHz clock. Using this recreated clock results in video artifacts. I am unable to determine the exact issue as the signal edges are still within the expected 68000 states. Logic analyzer output attached for future reference.

I am skipping this issue for now (but leaving it open), as there are other more important issues to deal with.

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

TheBajaGuy, 2023-10-02:
Hi Jason,
Thanks for the analyzer output, and the logic correction.  It's been ~30 years since I worked for GVP Tech Support, and a couple more (while there) since I hacked an A3001/25 to work on an A1000 or A500 expansion edge with 2x 86-pin L slot connectors soldered properly together, plus the synth of that missing clock logic (and created the _BOSS line logic to a pin on the 68000, because that's also missing on that connector on a German A2000).  FWIW - The 50MHz version actually worked fine on the A500, but the A1000's loose tolerances were shaky at 33MHz clocking.  My hacking moment resulted in Jeff Boyer (GVP Engineer) modifying the A2000 G-Force 030 into what became the GVP A530.

From your comment about the artifacts, I was looking at the E-clock, which feeds some motherboard resources (CIA registers, for one).  The output shows the E-clock transition is lining up on the fall of your CLK7-2630.  The native CLK7 signal is always low where the E-clock transitions.  As the E-clock is derivative from the 7M (& normally made in the 68000 when active), maybe it's generation from a different source (and the 30ns skew from the c1/c3 synth) has something to do with it?
Thought: As the German A2000 is kind of a corner case, and you also have the no-fallback to 68000 mode with them, maybe you could address a few issues in one.  An optional under-68000 PCB could have the missing gate needed to create _BOSS, hold the 68000 so it doesn't need to be removed/grant fallback, and you would have access to the 7M clock - if you wanted to steal it.  Possibly a headache to rev the board again to allow a 2-wire connection cleanly, though.
Low priority in any case, as you noted.
Robert

   On Monday, October 2, 2023 at 04:38:43 PM EDT, Jason Neus ***@***.***> wrote:

I looked at recreating the 7MHz system clock from the C1 and C3 clocks. The A500/A2000 Technical Reference recommends the equation "C1 XNOR C3" (pp. 89). XOR would result in the inverse of the 7MHz clock.

Unfortunately, this results in a delay of approximately 30ns between the recreated clock and the original A2000 7MHz clock. Using this recreated clock results in video artifacts. I am unable to determine the exact issue as the signal edges are still within the expected 68000 states. Logic analyzer output attached for future reference.

I am skipping this issue for now (but leaving it open), as there are other more important issues to deal with.

—
Reply to this email directly, view it on GitHub, or unsubscribe.
You are receiving this because you commented.Message ID: ***@***.***>

jasonsbeer, 2023-10-05:
> The output shows the E-clock transition is lining up on the fall of your CLK7-2630.  The native CLK7 signal is always low where the E-clock transitions.  As the E-clock is derivative from the 7M (& normally made in the 68000 when active), maybe it's generation from a different source (and the 30ns skew from the c1/c3 synth) has something to do with it?>

Could be. The data is latched on the falling edge of 68000 State 6 for reads from the A2000 board. This event is supposed to be synchronous with the falling edge of E. But, as you point out, there is some variance around that when the clocks are derived from different sources. The way to test this theory is to pull the 68000 and put it in "A"2000 mode. In that mode, the 2630 generates its own E signal based on the recreated clock. That should align everything. Something I will try in the near future.

I enjoyed reading about your GVP experiences. As a young man at the time, I felt anybody who was somebody purchased GVP peripherals. Although, I had to settle for lesser brands on the used market. 8^>

TheBajaGuy, 2023-10-05:
After I started at GVP, I was introduced to the person who ran the Philadelphia Amiga Users Group's 5-line BBS - an A2000 stuffed with our top gear ('040, serial cards, 'spare' hard disks), and he became one of my friends.  He referred to my job as working in the 'GVP Toy Factory' - and looking back, it kind of was.  While I wasn't paid all that much during that time of employ - I was 20 when I started - there was an education and experience to be had that no school could have ever provided.  It was a frontier, of sorts.  The 'wild wild west' of computing.  The job had lots of stress, but it was also lots of fun.

I dropped the last run you posted into Paint, zoomed in, and there are points where the synth CLK7-A2630 is still high as E is falling (4th red line, pasted below as an example), but the CLK7 is clearly low.  I eye-balled the rest of the capture, and it looks like several others are lined up like much that one.

I was updating the BBOAH's Amiga 2000 page in the past week, and it reminded me of Dave Haynie mentioning some changes he made for the B2000, including how buffering around the CPU slot, particularly clocks, is more beefed up than on the A2000.  I don't recall all the details of the (first) GVP A3001, but there were 4 jumpers to change on it when used in the German A2000, and the 68000 was of course removed.  I never had the schematics, but the J12/13/14 changes I believe are related to the C1/C3 (connect) and 7M (disconnect).  I think J10 does something to compensate for the missing 68000.  The other reason I mention this is the GVP A3001 front card also could use the C= ROMs for Unix or Boot Selection, and we had an IDE interface, too.  Sadly, our board was out before the finalized the AT-IDE standard.  The final timing on ours was off frm that spec.  GVP was quite small at the time - I was the 9th employee hired in late 1989 - so another board rev was not an option for quite awhile.  The drives that did work dried up by late 1990, and so the Combo cards with DPRC DMA SCSI became the next generation.

I wish I had the time to get one of these boards built and give it a run.  I have quite a stack of GVP and other Z2/Z3 cards in my collection.  I participate in the Amiga OS Beta Test group (3.1.4, 3.2, etc) as time allows.  I use my 'collection' to test things like AutoConfig behavior (in the OS) with fast accelerators.  I also have produced the GuruROM v6 (for GVP and A2091/590) from Ralph Babel.  Unfortunately, I'm very behind on producing them for the waiting list on Aminet - life happens, personal priorities, and all that, as I am sure you know.

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

jasonsbeer, 2023-11-05:
Revision 4.0.x fixes this issue.

jasonsbeer, 2023-11-05:
Revision 4.0.x fixes this issue.

Closed 2023-11-05.

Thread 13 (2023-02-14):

Enable Zorro 2 RAM In 68000 Mode

jasonsbeer, 2023-02-14:
Currently, the Zorro 2 RAM on the N2630 is only available in 68030 mode. It should be possible to enable it in 68000 mode with little or no undesirable side effects.

Investigate feasibility and implement.

TheBajaGuy, 2024-01-16:
Tossing in a comment - maybe something I touch on could help.  I assume your Z3 RAM is your first AutoConfig PIC in accelerator mode.  I'll then assume that the Z2 FastRAM PIC follows it.  I don' know if you have a PIC for the IDE interface in that sequence somewhere, but I'll assume it could be.  Upon selection of the 68000 mode, you would need to check that your RAM state machine remains active against the 68000 bus (and any buffers default to facing it as a slave).  You would need to shut/jump over the Z3 RAM and/or the IDE interface PICs after _reset comes up.  Also, read your 0MB and 4/8 MB card size jumper.  A user would likely connect a DP(DT) switch to effect their choice.

I dunno if there is an available jumper for it, so due to possible complexity/limitations, it may need to be effected in the firmware - one for inclusion of 68000 fallback memory, and one that does not.  The presence of the AutoConfig Fast memory can throw off some poorly programmed early games.

I don't have a card, but am considering getting one with the PGA FPU layout (if anyone else is getting a few boards made).  I think I have a fair number of the parts already in my spares collection.

tkurbad, 2025-03-14:
I tried my luck with the VHDL for U601. One of the major problems to overcome is that the Autoconfig routine is based on signals coming from the 68030, namely /AS and /DS.

While /UDS and /LDS of the 68000 are routed to U601, the original /AS is not. It is available on U600 only. /AS could probably be skipped by "guessing" the Autoconfig address phases. However, there still needs to be a smart way to determine when the address buffers need to be open for RAM and IDE.

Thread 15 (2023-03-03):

Problem with many ZorroII Cards

transi01, 2023-03-03:
Hello Jason,

we have issues with ZorroII Cards which seems to be a problem with ovr / dtack
The cards with problems are:
X-Pert Merlin Graphics card
Georg Braun / Matthias Heinrichs GrakaP2++ (Picasso II Clone using CL-GD5434 Chip)
E3B Deneb USB Card.  USB is working, but when trying to flash the flash, computer freezes.

The efect for all cards is that the computer seem to freeze but it still does something veeeery, veeery slow.

All above cards use ovr / dtack function to sync i/o

Thanx for investigation!
Cheers,

// Thomas

jasonsbeer, 2023-03-03:
I do not have access to those cards for testing. Are they DMA devices? Are there any relevant technical documents or timing diagrams available?

transi01, 2023-03-03:
No, they are no DMA devices. Cause of some deeper info's I might pass you through to a friend of mine, which has designed a bunch of new USB Cards for Amiga's. He might be able to help you in locating the problem, he also has a N2630 for testing.

are you able to send me an e-mail to: tlohmann@transi-productions, and I'll pass the contact over to mattymuc ?!

// Thomas

jasonsbeer, 2023-03-03:
That sounds good. I will send you an email.

transi01, 2023-03-03:
Here you might find info's about how to handle the signals:
http://amigadev.elowar.com/read/ADCD_2.1/Hardware_Manual_guide/node02A2.html

jasonsbeer, 2023-03-03:
Outside of DMA activities, Gary generates all _DTACK signals. That's why I asked. The cards you mention not DMA devices, but they still assert _OVR? The N2630 only generates _DTACK during DMA, meaning the bus grant must be asserted.

transi01, 2023-03-03:
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

jasonsbeer, 2023-03-03:
Linking to descriptions of the _DTACK signal is not useful in this context. Gary generates _DTACK for all cycles except DMA. Since these devices are not DMA, generation or timing of Gary's _DTACK is not the problem.

coriolis1986, 2023-08-20:
Any news about this issue? I also have a lot of problems with a Zorro expansions.

lordwolfchild, 2023-08-21:
I'm afraid I'll have to agree with this. The N2630 is a great design and I really enjoyed building and experimenting with it. But it just does not work well (yet!) with some Zorro II Cards.

I have massive Problems with BuddaIDE and XSurf 100, which I would really like to keep. The BuddhaIDE works like a charm for an undetermined amount of time, then it just hangs while accessing. The X-Surf can be initialized, but a soon as network traffic is generated, everything comes to a halt. The OS is (in both cases) still there, taking commands and everything, but the hardware is blocked and rather unresponsive.

I do not know enough about the Zorro II bus to diagnose and find the problem myself, though. :(

The N2630 by itself works like a charm, though.

jasonsbeer, 2023-08-22:
I updated the U600 logic to consider delayed assertion of _DTACK in the 68000 state machine. This update can be found in the DEV branch, under logic. I was told this helped, but some issues still exist. You can try the "X" and "X1" logic to see if it helps. Link below.

The only way to figure this out is to either gain access to the hardware in question or have someone supply timing output from a logic analyzer. The hard reality is I do not have any of the hardware devices mentioned and I have no immediate plans to purchase them. This project has cost a lot of money to develop, and the line has to be drawn somewhere.

If someone can supply output from a logic analyzer or can lend an example of the hardware in question, that would help to move this issue forward. Flagging this issue with a help needed flag.

https://github.com/jasonsbeer/Amiga-N2630/tree/Dev/Logic/JED/U600

lordwolfchild, 2023-08-24:
I tried both variants, "X" seems to work fine, "X1" seems unable to boot with BuddhaIDE. I will try some different hardware configurations and try to give some feedback which cards do work with the updated _DTACK handling. Thank you very much for all the work you invested in this project! Seeing the old 2000 performing this great today is sort of "Heaven" indeed!

jasonsbeer, 2023-08-24:
@lordwolfchild That is great information. Thank you.

jasonsbeer, 2023-11-05:
Fixed with firmwares released on November 5, 2023.

Closed 2023-11-05.

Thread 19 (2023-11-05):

Documentation Items

TheBajaGuy, 2023-11-05:
Some items in the documentation to backfill information on, as it seems to be a little ambiguous, or is missing:

IDE section, J905 setting, implies the option of using a Cable Select (CS) pair of IDE devices.  I will make the assumption that CS is a  functional feature at this point?  If that is true, then it is implied by other wording (but not explicit) that the onboard CF interface cannot be used with the CS setting, as it is a non-CS device?  Save a few support questions by mentioning it.  It should also be written out that both potential IDE-cable devices must also support CS, have the proper cable, and be set for CS operations.

AMIX, as I always understood from the rare encounters I had, only supported the 33C93A SCSI interface of the A3000 and the A2091 for both tape and SCSI disk I/O operations.  I don't believe there is any Gayle-like IDE interface support in it, as CPU-driven disk interfaces are usually shunned by Unix/POSIX operating systems.  It may be worth a mention of having an AMIX-supported SCSI controller, such as the A2091, in the system lest someone makes an assumption that the onboard IDE may work.

Informational:

Although I believe it has become a stale build by now, my brother used to run the 68K version of NetBSD on the GVP 68030's and Series II SCSI cards.  My understanding is that the 68K NetBSD would support ANY 68030 accelerator, and at least any Zorro-configured FastRAM.  It also supported at least the 33C93A SCSI chip in an AutoConfig PIC, which meant at least the C= A2091 and the GVP Series II SCSI interfaces.  I know it was base-compatible with the A2630-based A2500 and the A3000D/T, so should be compatible with the N2630's accelerator.  I have no info on IDE support it may or may not have had.

Zorro II/III RAM settings - Has OS 2.04/2.05 for the 16-bit machines (A2000) been checked to see if it supports a Zorro III AutoConfig PIC?  I know the support for this was in the Amiga OS 3.1 and later releases.  I am not sure it was in 2.04/2.05.  It may be a good idea to check and note it.  I doubt the Zorro III FastRAM setting will work/may even crash under Kickstart 1.3, as Zorro III never existed under OS 1.3 when it was released for the 68000 machines.  The Zorro-II settings will work in all OS versions.

jasonsbeer, 2023-11-15:
Thanks for the suggestions and information. Comments below. Its good to have the documentation peer reviewed. I will close this issue as complete, but feel free to reopen or start a new one if you see anything else.

> IDE section, J905 setting, implies the option of using a Cable Select (CS) pair of IDE devices. I will make the assumption that CS is a functional feature at this point? If that is true, then it is implied by other wording (but not explicit) that the onboard CF interface cannot be used with the CS setting, as it is a non-CS device? Save a few support questions by mentioning it. It should also be written out that both potential IDE-cable devices must also support CS, have the proper cable, and be set for CS operations.

I edited the IDE section to enhance clarity around this.

>
> AMIX, as I always understood from the rare encounters I had, only supported the 33C93A SCSI interface of the A3000 and the A2091 for both tape and SCSI disk I/O operations. I don't believe there is any Gayle-like IDE interface support in it, as CPU-driven disk interfaces are usually shunned by Unix/POSIX operating systems. It may be worth a mention of having an AMIX-supported SCSI controller, such as the A2091, in the system lest someone makes an assumption that the onboard IDE may work.

I added this and a link to the AMIX page.

> Although I believe it has become a stale build by now, my brother used to run the 68K version of NetBSD on the GVP 68030's and Series II SCSI cards. My understanding is that the 68K NetBSD would support ANY 68030 accelerator, and at least any Zorro-configured FastRAM. It also supported at least the 33C93A SCSI chip in an AutoConfig PIC, which meant at least the C= A2091 and the GVP Series II SCSI interfaces. I know it was base-compatible with the A2630-based A2500 and the A3000D/T, so should be compatible with the N2630's accelerator. I have no info on IDE support it may or may not have had.

Thanks for the information. The current NetBSD Amiga build supports the 68020 and greater and the A1200 built in IDE, which is Gayle. Sounds like it should work with the N2630, but we have not specifically tested it nor have I heard it discussed.

> Zorro II/III RAM settings - Has OS 2.04/2.05 for the 16-bit machines (A2000) been checked to see if it supports a Zorro III AutoConfig PIC? I know the support for this was in the Amiga OS 3.1 and later releases. I am not sure it was in 2.04/2.05. It may be a good idea to check and note it. I doubt the Zorro III FastRAM setting will work/may even crash under Kickstart 1.3, as Zorro III never existed under OS 1.3 when it was released for the 68000 machines. The Zorro-II settings will work in all OS versions.

Z3 AUTOCONFIG works with KS2.04 and newer. We tested it pretty well.

It is recommended in the documentation to disable Z3 RAM on the N2630 when using KS1.x. This 'disable' skips the AUTOCONFIG process, but the RAM still responds in the Z3 address space. Testing on my machines indicates it is not necessary to disable Z3 AUTOCONFIG in this case, but I feel it is best practice.

Closed 2023-11-15.

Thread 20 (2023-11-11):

N2630 is not compatible with Agnus 8371

coriolis1986, 2023-11-11:
Hi all.

Just tried to run my A2000 with N2630 and Agnus 8371. It crashes with an old firmware. I reflashed U600-U602 to latest versions and my Amiga just refuse to start anymore.

LIV2, 2023-11-12:
Hi @coriolis1986

Did you previously have an 8372 fitted and did it work with the N2630 in this machine?

If you did swap from an 8372 to 8371 did you also change J101 to match this and close J500?

What version of Kickstart are you using and do you have the 68000 installed in the motherboard?

coriolis1986, 2023-11-12:
The original configuration of this A2000 has an 8371. I replaced it for a 8372, which I took out from Amiga 500. And N2630 works perfectly after this.

I have a Kickstart switcher (1.3, 2.04, 3.1, 3.2.1) and any of them works with an accelerator. Also the 68000 installed in the motherboard.

Both of the 8371 and 8372 works with 68000.

So only when the Agnus is changed, N2630 started or stopped to work.

I'll try to look to the jumpers on motherboard (ver 4.4). May be some of them will change the situation.

jasonsbeer, 2023-11-14:
Does your board have the 1 meg chip RAM mod? Testing team reports 8370 (NTSC version of 8371) works with the N2630 in a Rev 6 board.

jasonsbeer, 2023-12-11:
The testing team was not able to reproduce this situation. Unless further information surfaces, there is not enough information to act upon. Open again if additional information surfaces.

Closed 2023-12-11.

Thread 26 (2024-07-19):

PDIAG shold be connect to all IDE ports

LordZodiac76, 2024-07-19:
Hi Jason,

in the german A1K forum i have found a hint that all IDE PDIAG connections should be connected so all IDE devices can communicate with each other.

https://www.a1k.org/forum/index.php?threads/78485/page-73#post-1781294
https://www.a1k.org/forum/index.php?threads/78485/page-74#post-1781338

cheers Marco

jasonsbeer, 2024-07-20:
Thanks for pointing that out. They are correct. I'll mark this as an enhancement as it seems to work without this connection. If there are some issues that can be attributed to this, I will move it to bug.

From the ATA-4 Spec:

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

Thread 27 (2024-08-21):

X1 and X2 Values Are Reversed

jasonsbeer, 2024-08-21:
The clock frequency values are reversed in the schematics and iBOM. The correct values are X1: 50MHz, X2: 25MHz.

X1 always drives the CPU clock and will drive the FPU clock when J202 is set by shorting pins 1 and 2.
X2 will drive the FPU only when J202 is set by shorting pins 2 and 3.

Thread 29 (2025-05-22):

Add to working devices: Zorro-IDE-LAN-CP

HomeLate, 2025-05-22:
Just to let you know, the Zorro-IDE-LAN-CP card by Matthias Heinrichs works without problems.

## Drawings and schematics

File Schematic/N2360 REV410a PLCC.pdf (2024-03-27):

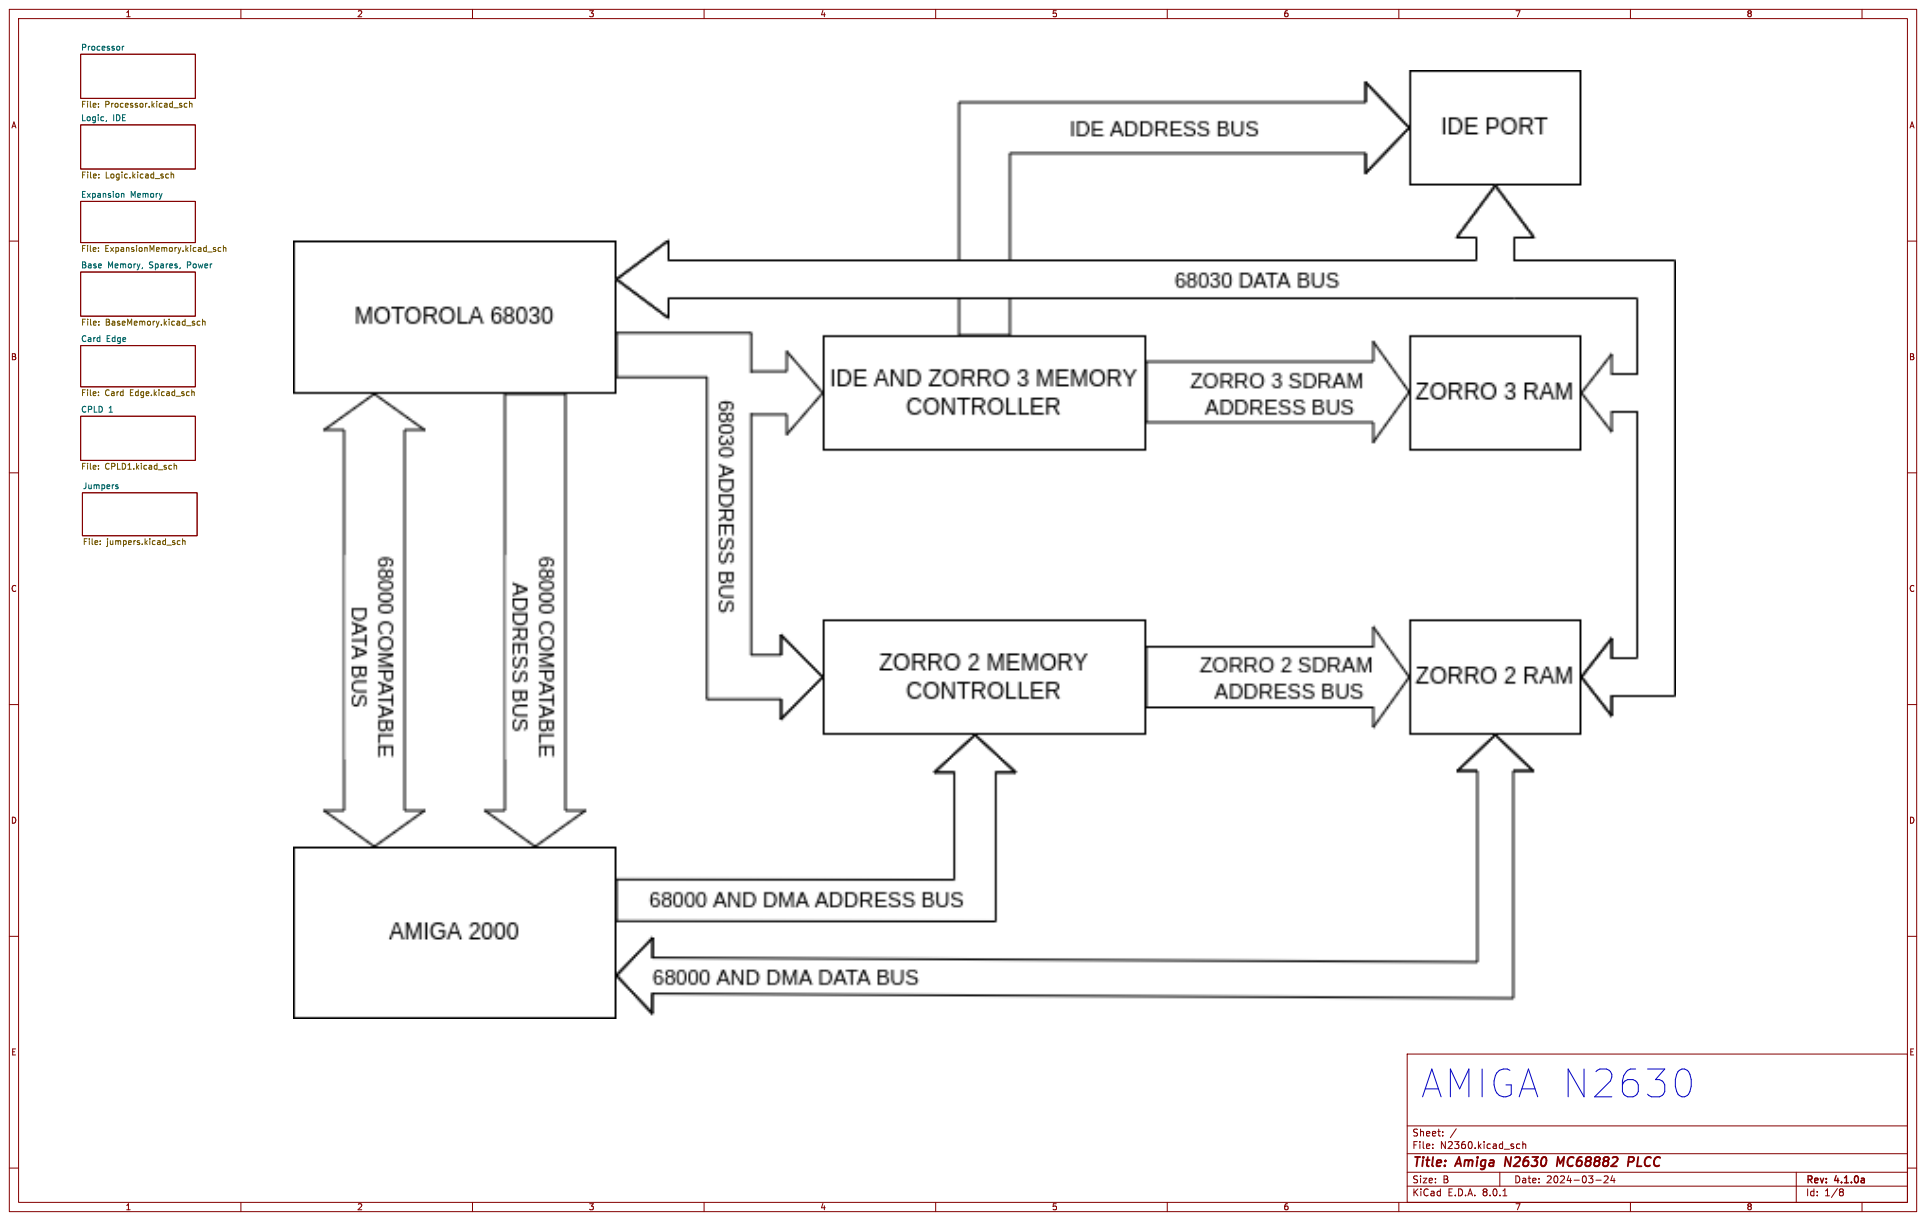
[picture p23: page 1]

Processor File: Processor.kicad_sch Expansion Memory File: ExpansionMemory.kicad_sch Card Edge File: Card Edge.kicad_sch Base Memory, Spares, Power File: BaseMemory.kicad_sch

File: N2360.kicad_sch Sheet: /
Id: 1/8 Title: Amiga N2630 MC68882 PLCC

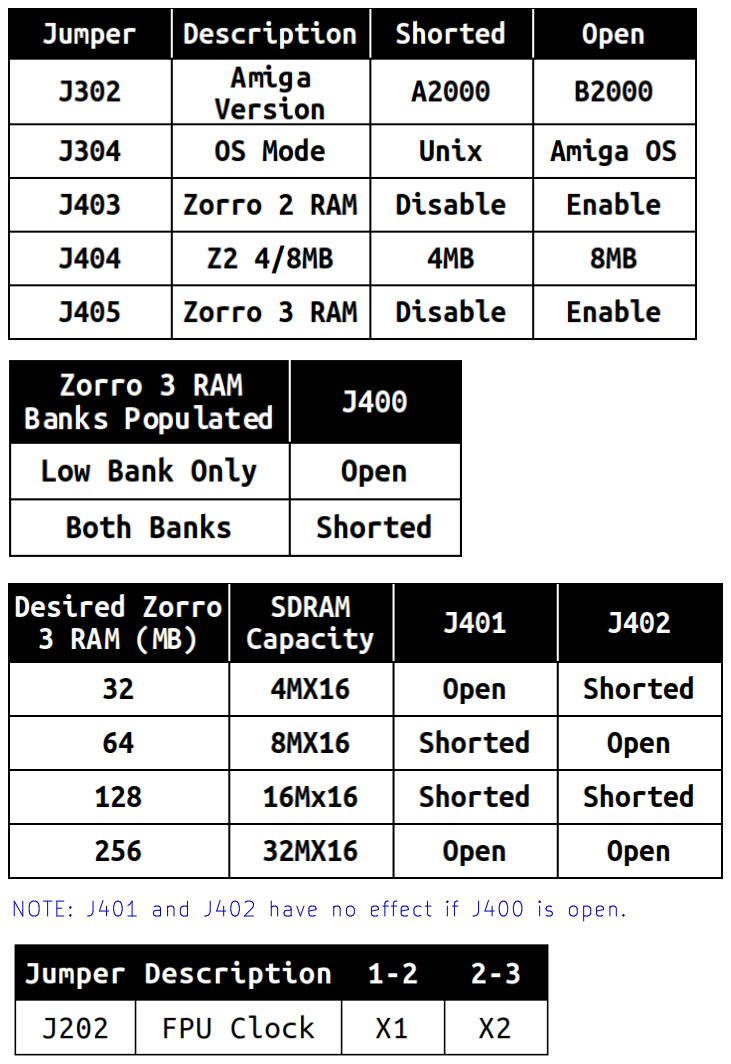
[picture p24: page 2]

File: jumpers.kicad_sch Sheet: /Jumpers/
Id: 1/8 Title: Amiga N2630 MC68882 PLCC

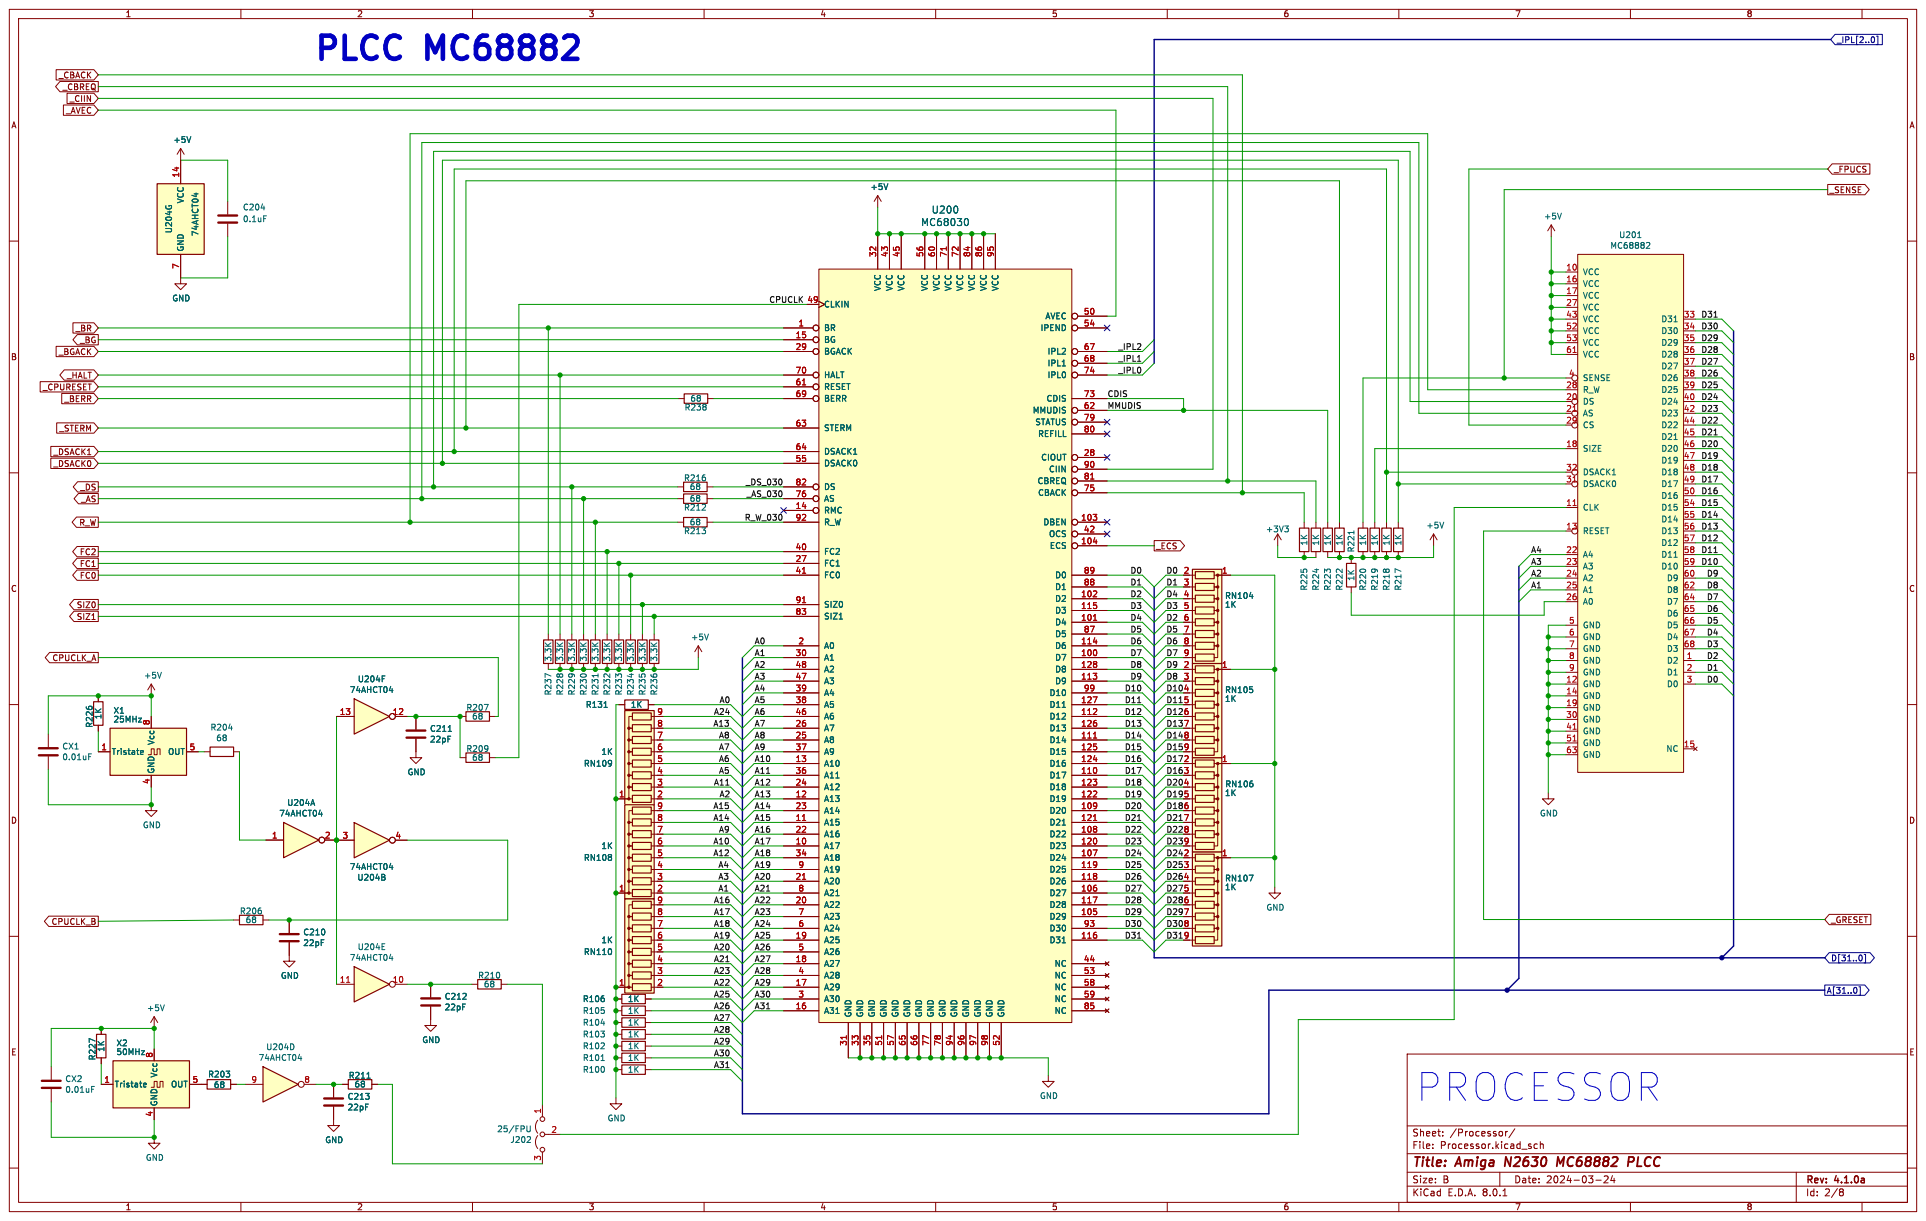
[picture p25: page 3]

VCC 10 CLK 11 GND 12 RESET 13 GND 14
50 GND 51

File: Processor.kicad_sch Sheet: /Processor/ C210

Id: 2/8 Title: Amiga N2630 MC68882 PLCC

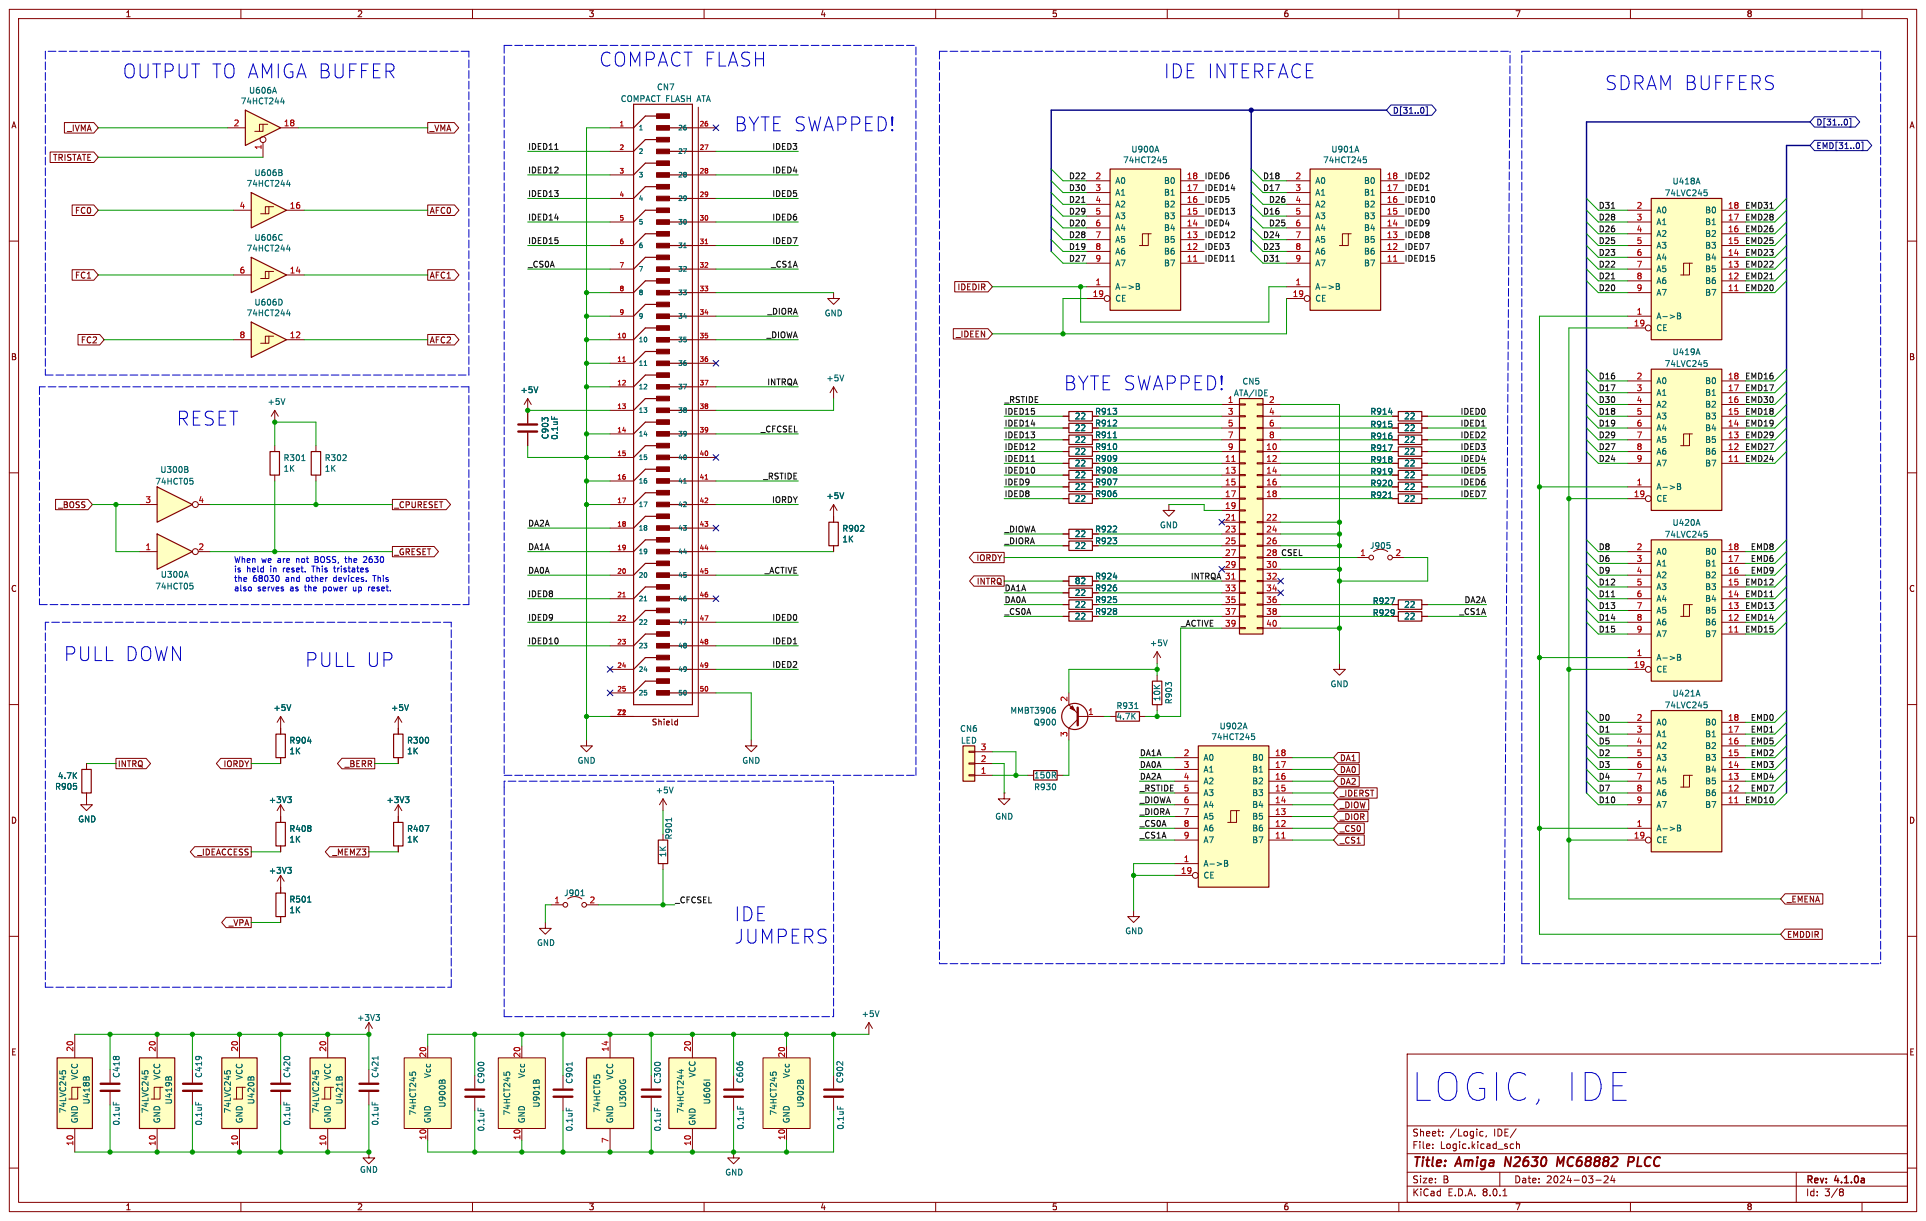
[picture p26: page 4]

OUTPUT TO AMIGA BUFFER

When we are not BOSS, the 2630
is held in reset. This tristates

Id: 3/8 Title: Amiga N2630 MC68882 PLCC

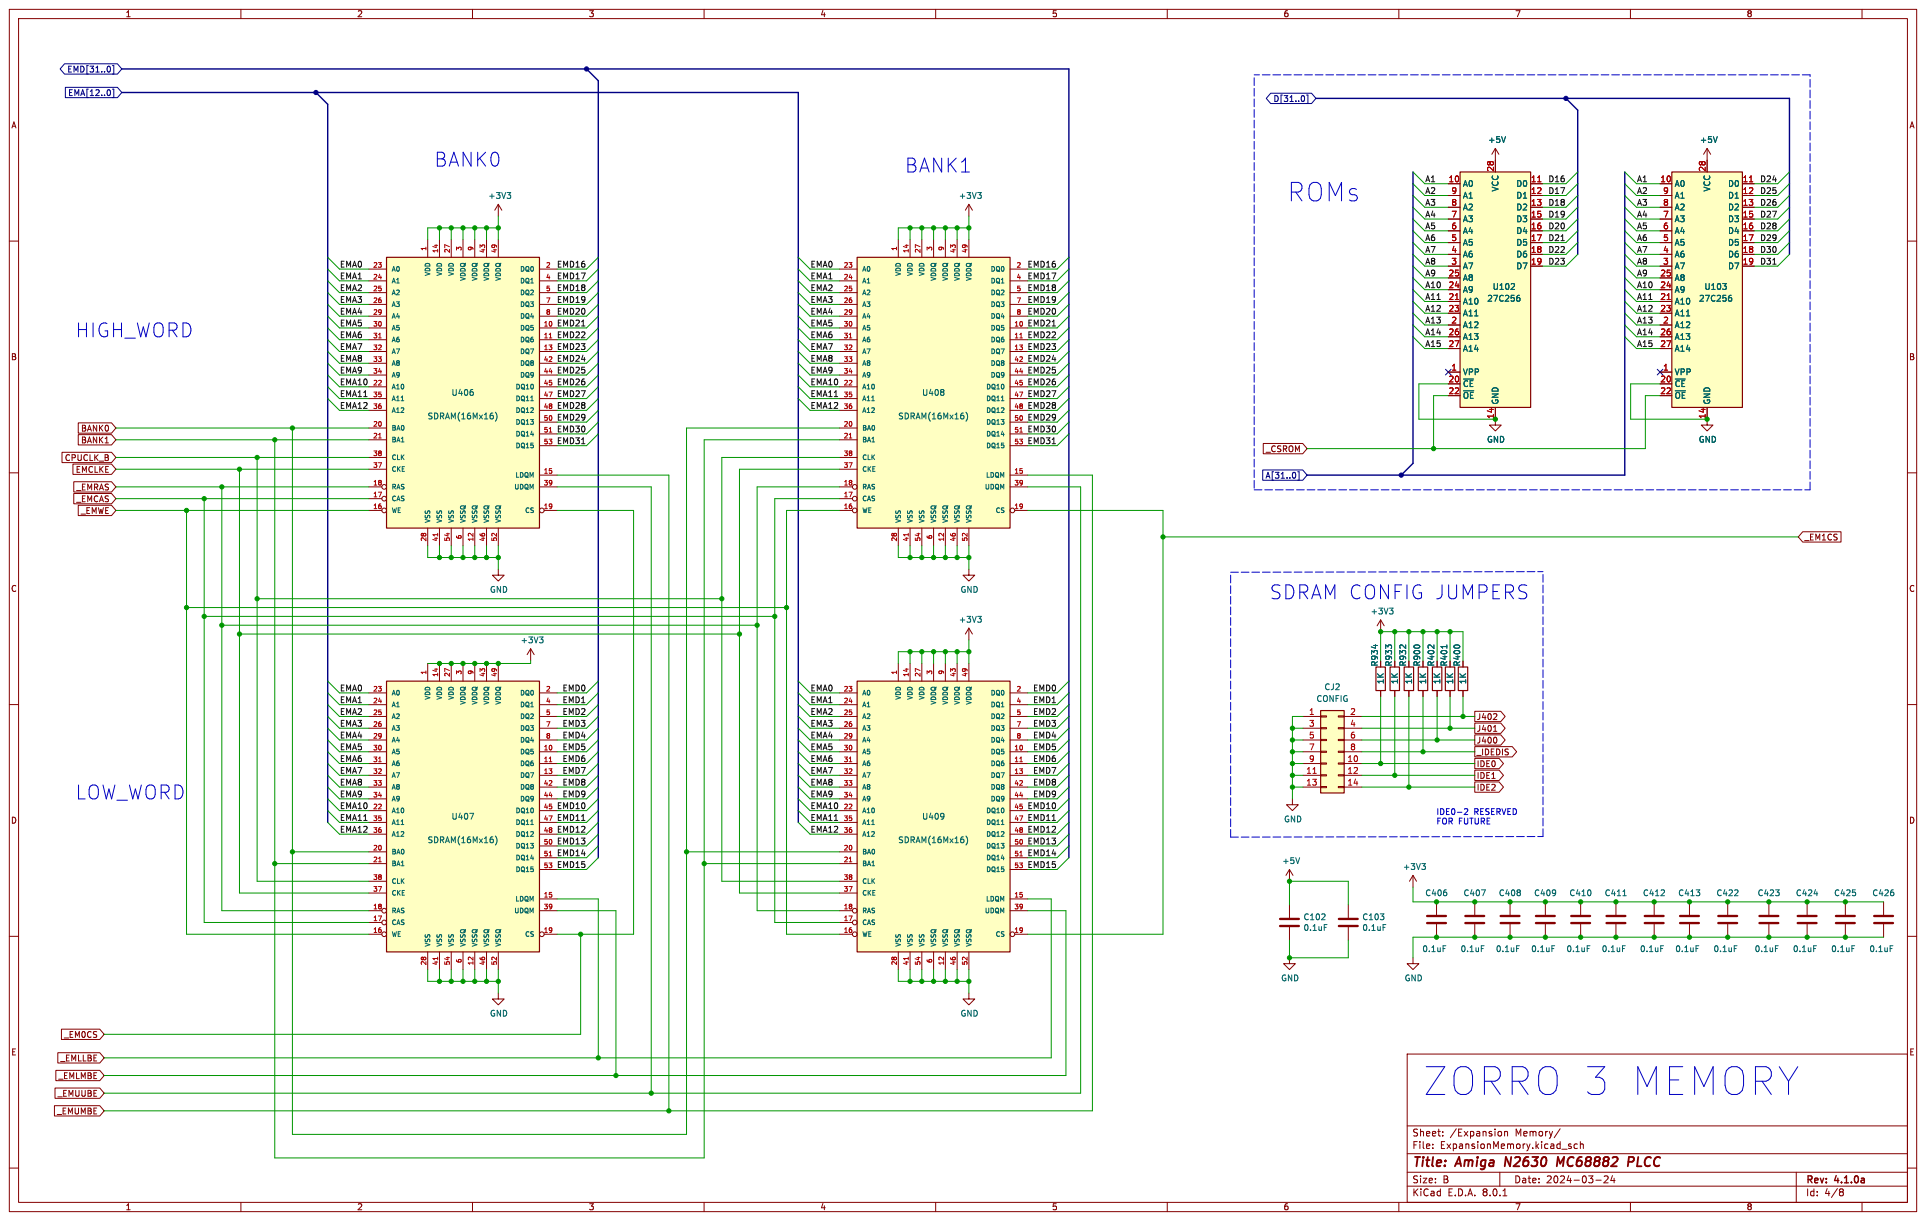
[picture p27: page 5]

Id: 4/8 Title: Amiga N2630 MC68882 PLCC

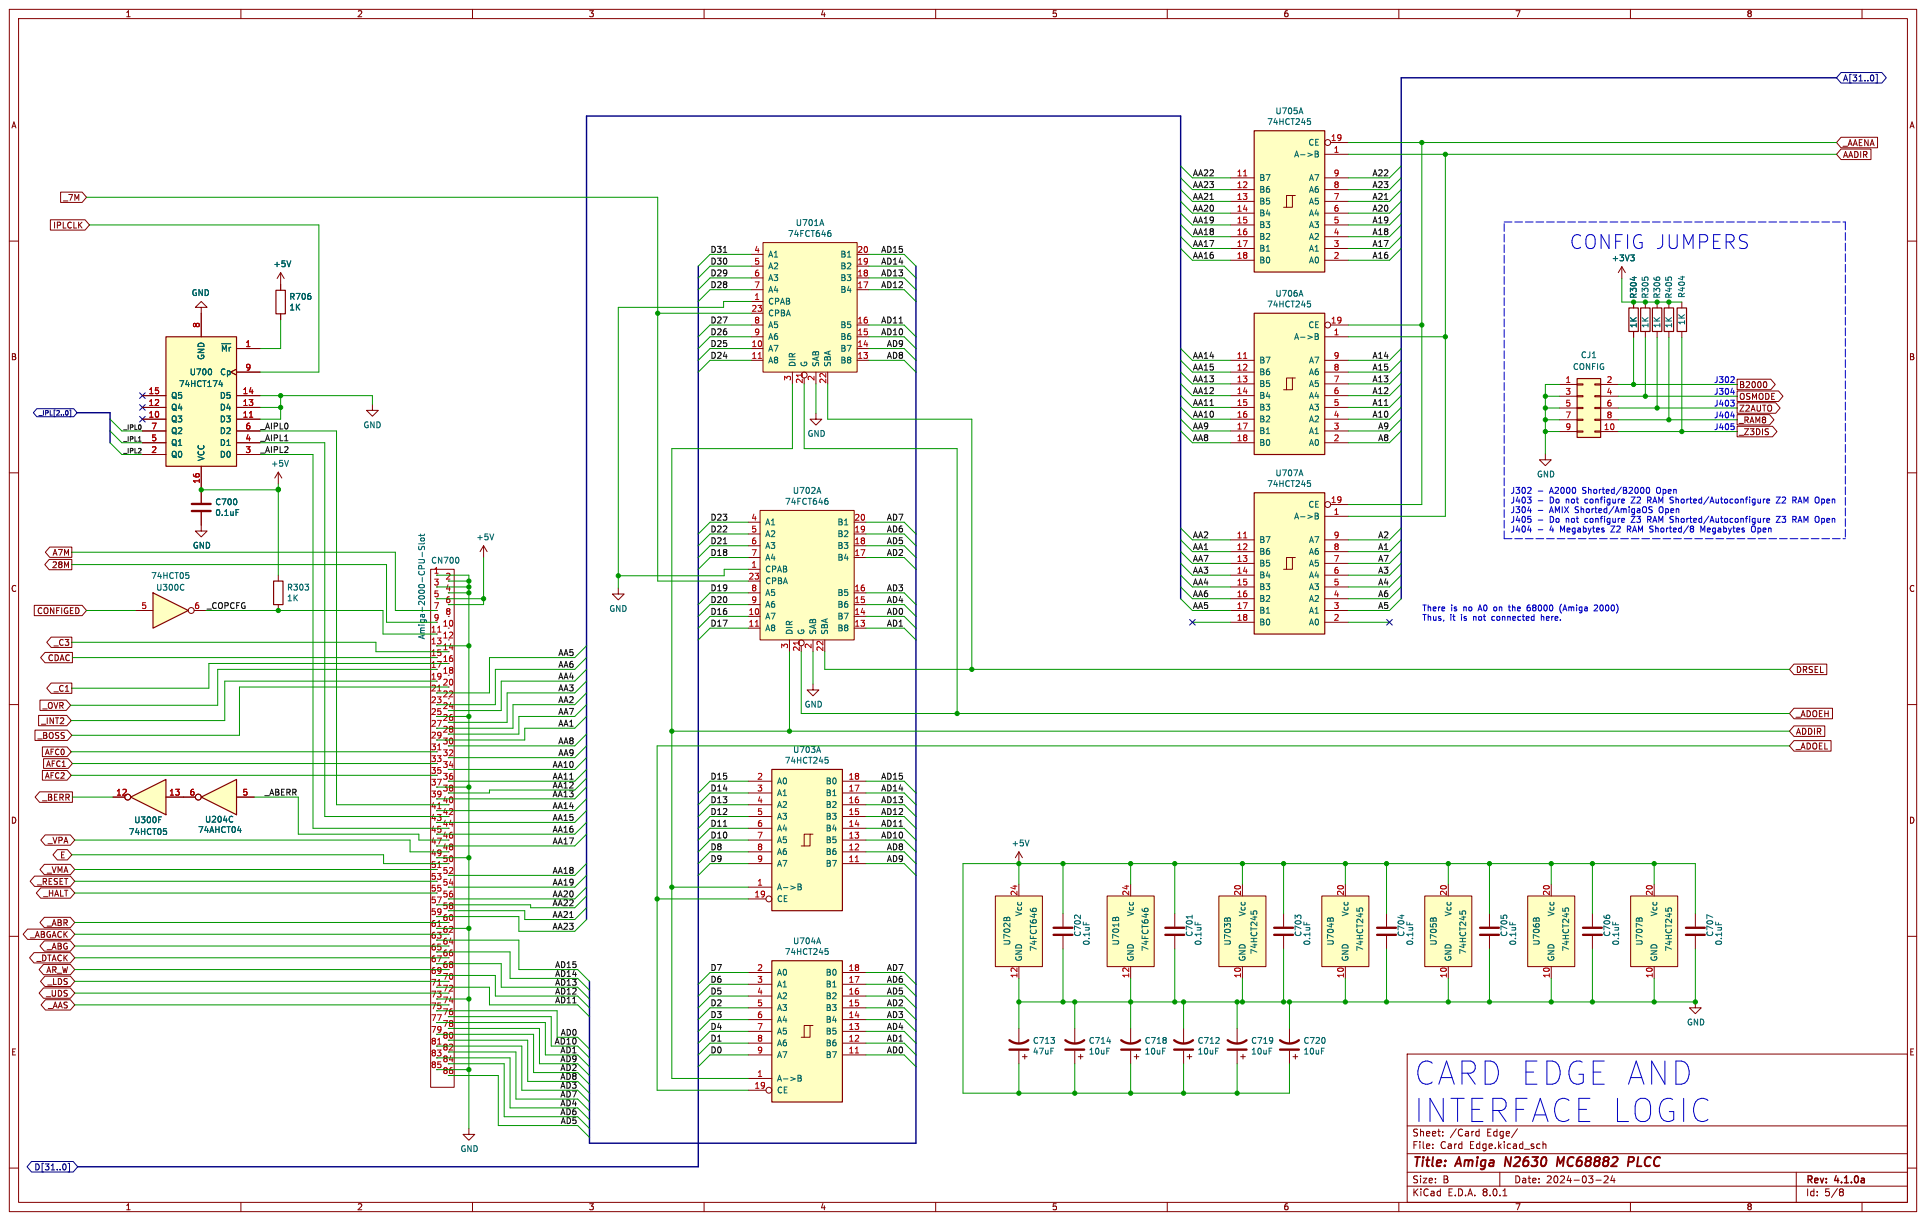
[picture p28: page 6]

Id: 5/8 Title: Amiga N2630 MC68882 PLCC

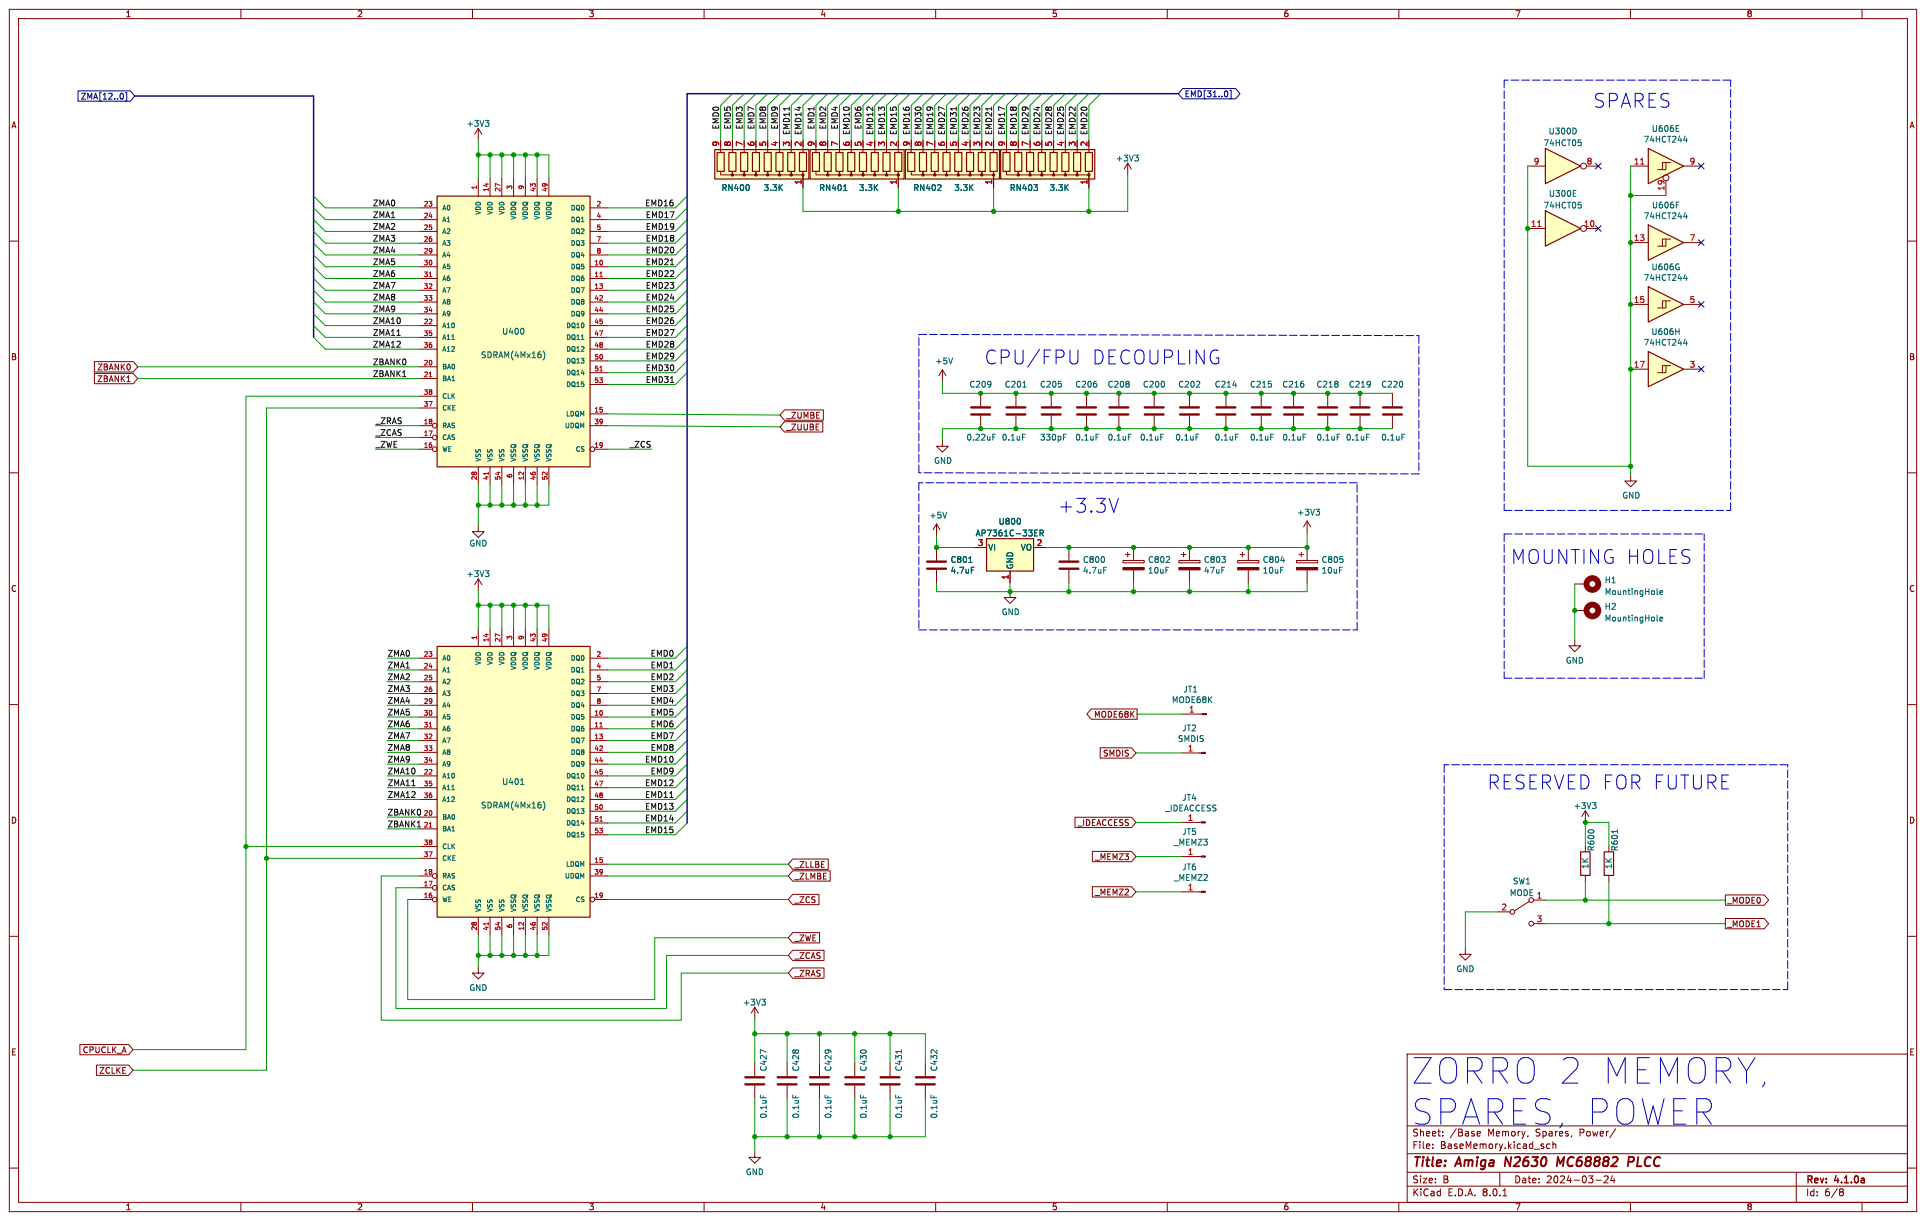
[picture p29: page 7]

Id: 6/8 Title: Amiga N2630 MC68882 PLCC

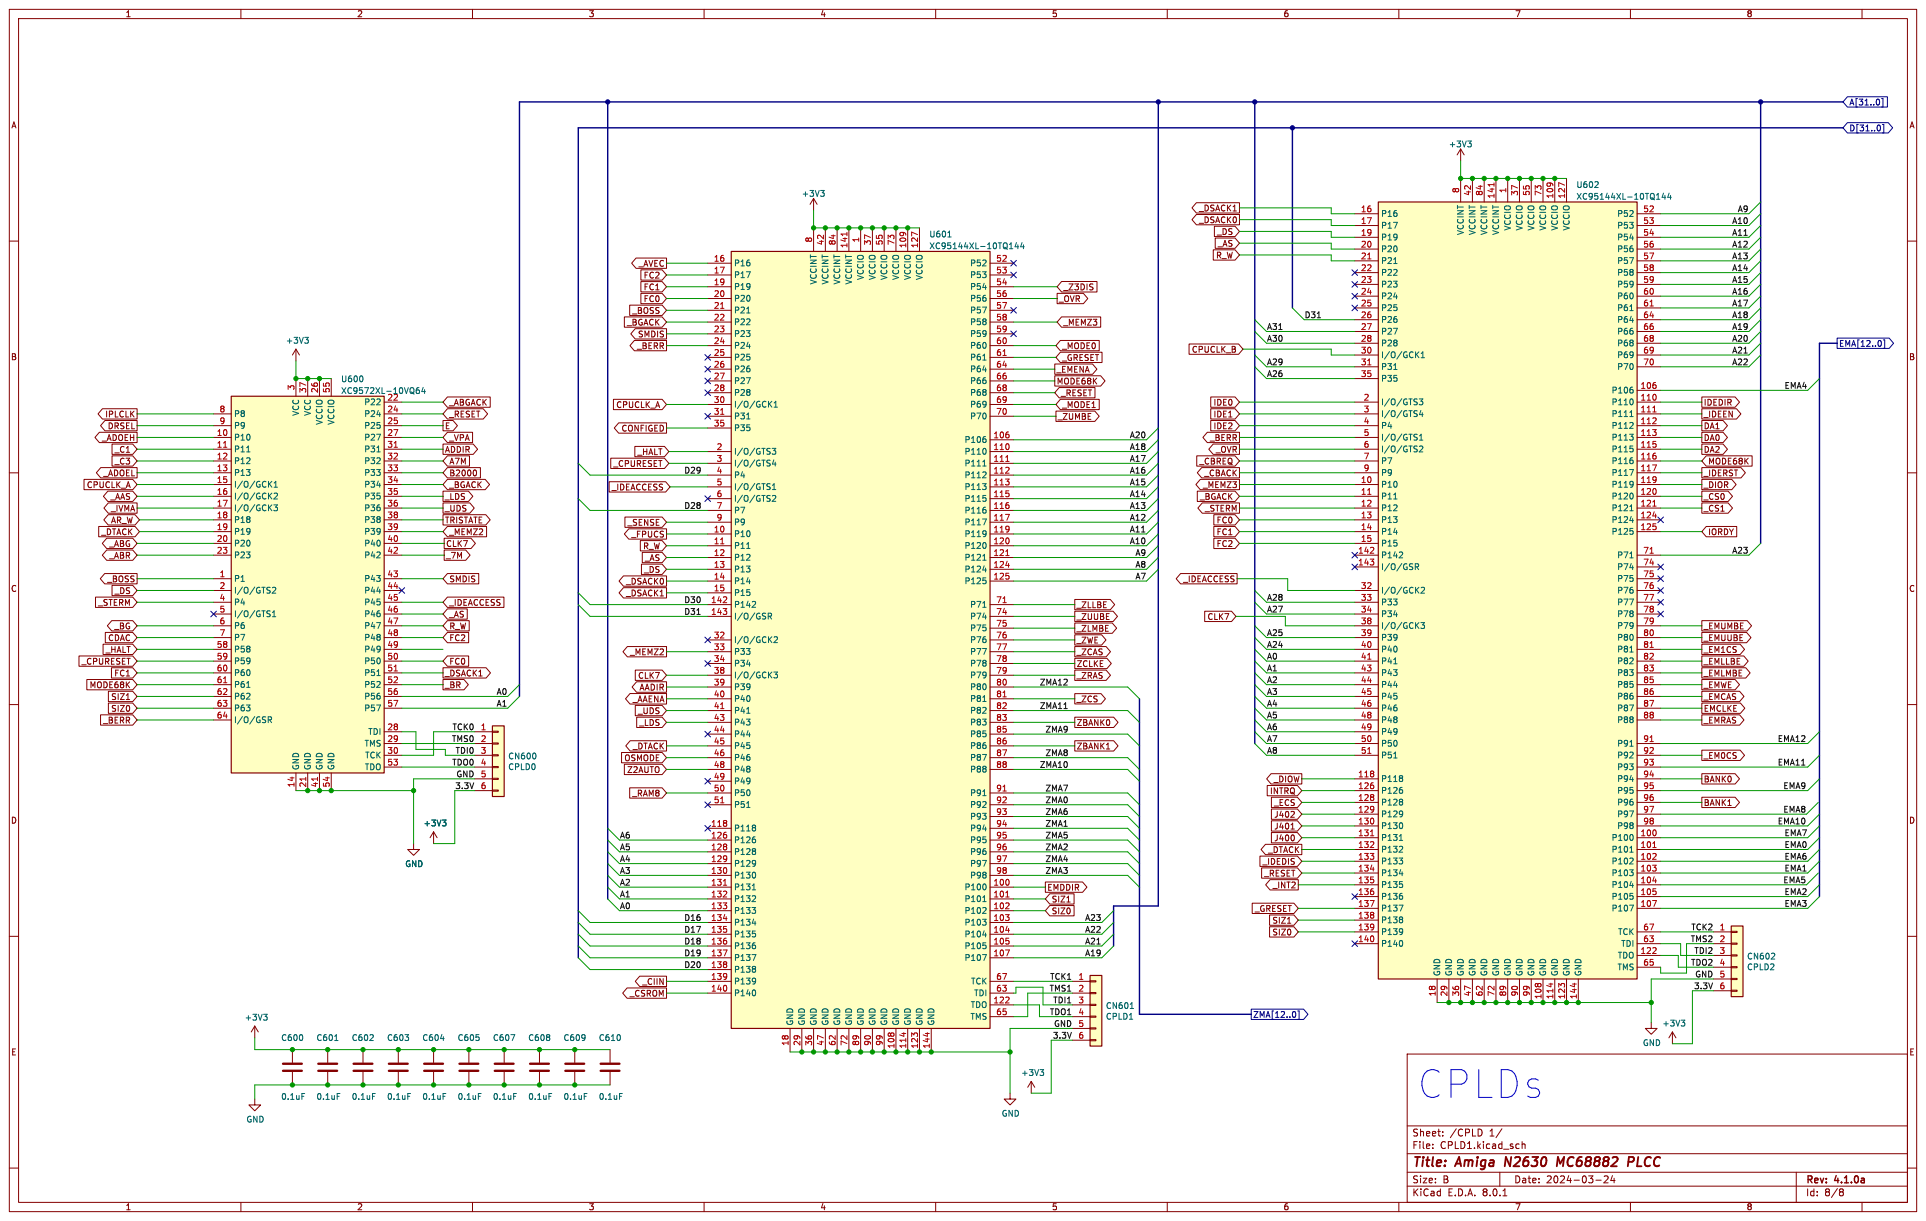
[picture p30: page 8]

Id: 8/8 Title: Amiga N2630 MC68882 PLCC

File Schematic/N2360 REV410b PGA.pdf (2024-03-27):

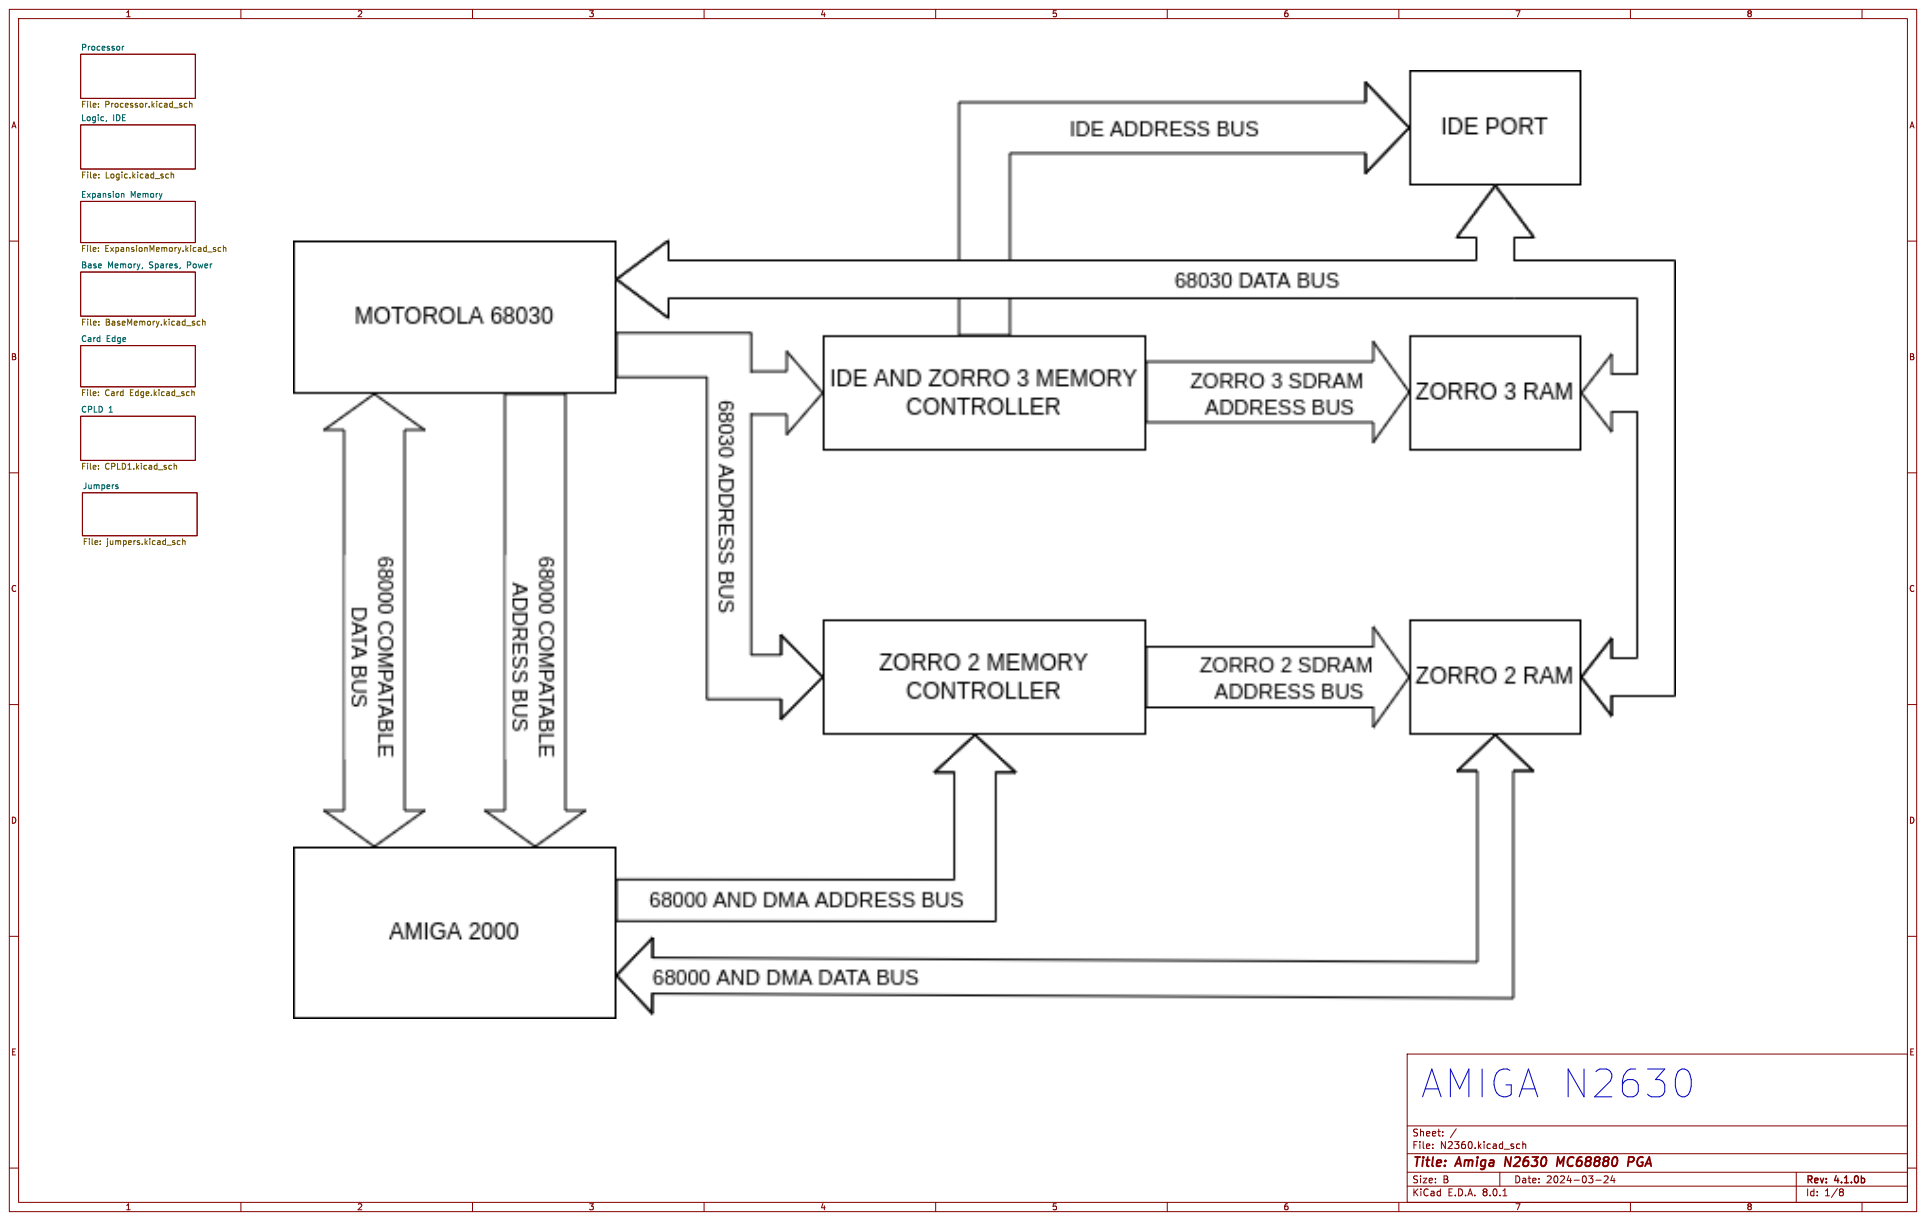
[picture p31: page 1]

Processor File: Processor.kicad_sch Expansion Memory File: ExpansionMemory.kicad_sch Card Edge File: Card Edge.kicad_sch Base Memory, Spares, Power File: BaseMemory.kicad_sch

File: N2360.kicad_sch Sheet: /
Id: 1/8 Title: Amiga N2630 MC68880 PGA


File: jumpers.kicad_sch Sheet: /Jumpers/
Id: 1/8 Title: Amiga N2630 MC68880 PGA

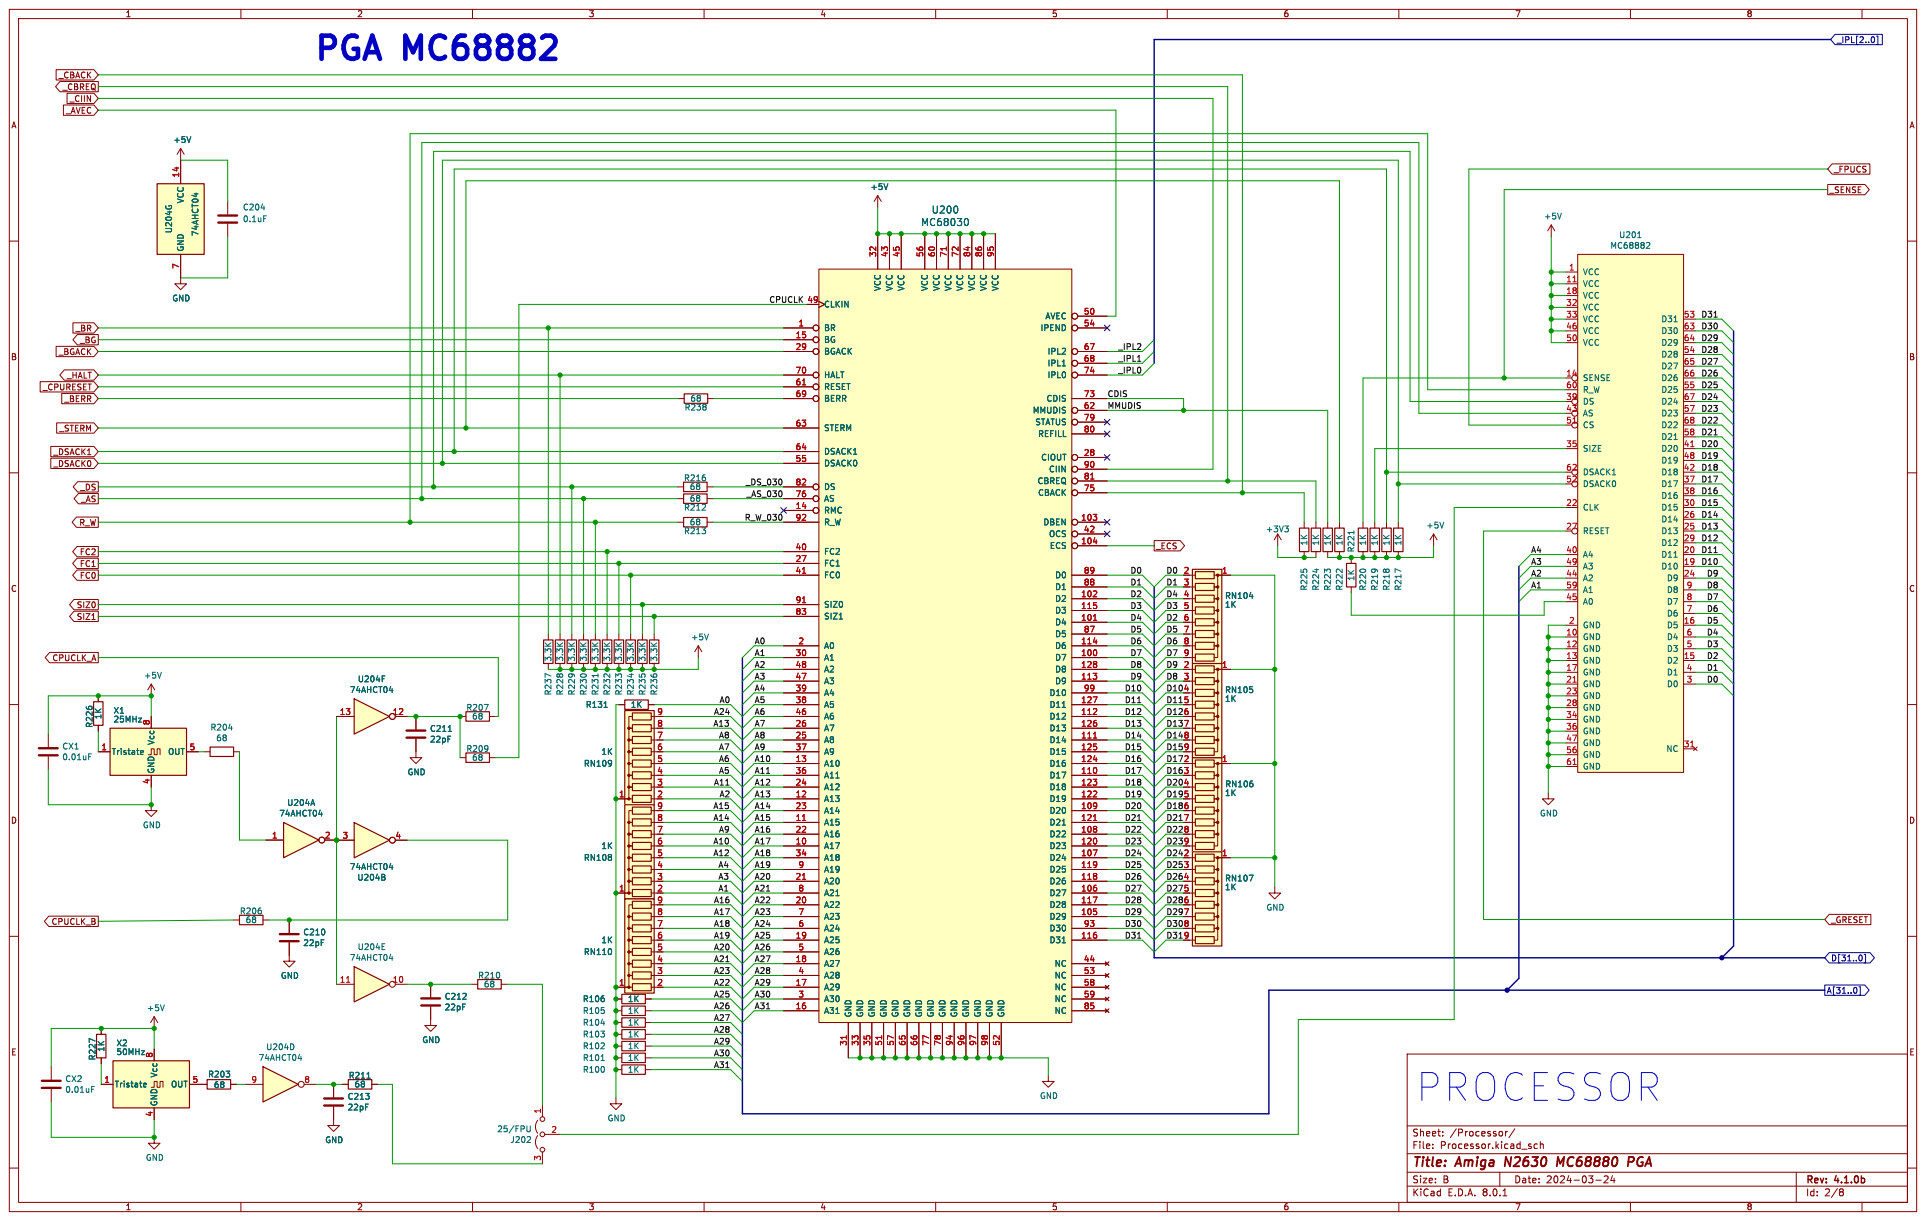
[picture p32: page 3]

Id: 2/8 Title: Amiga N2630 MC68880 PGA

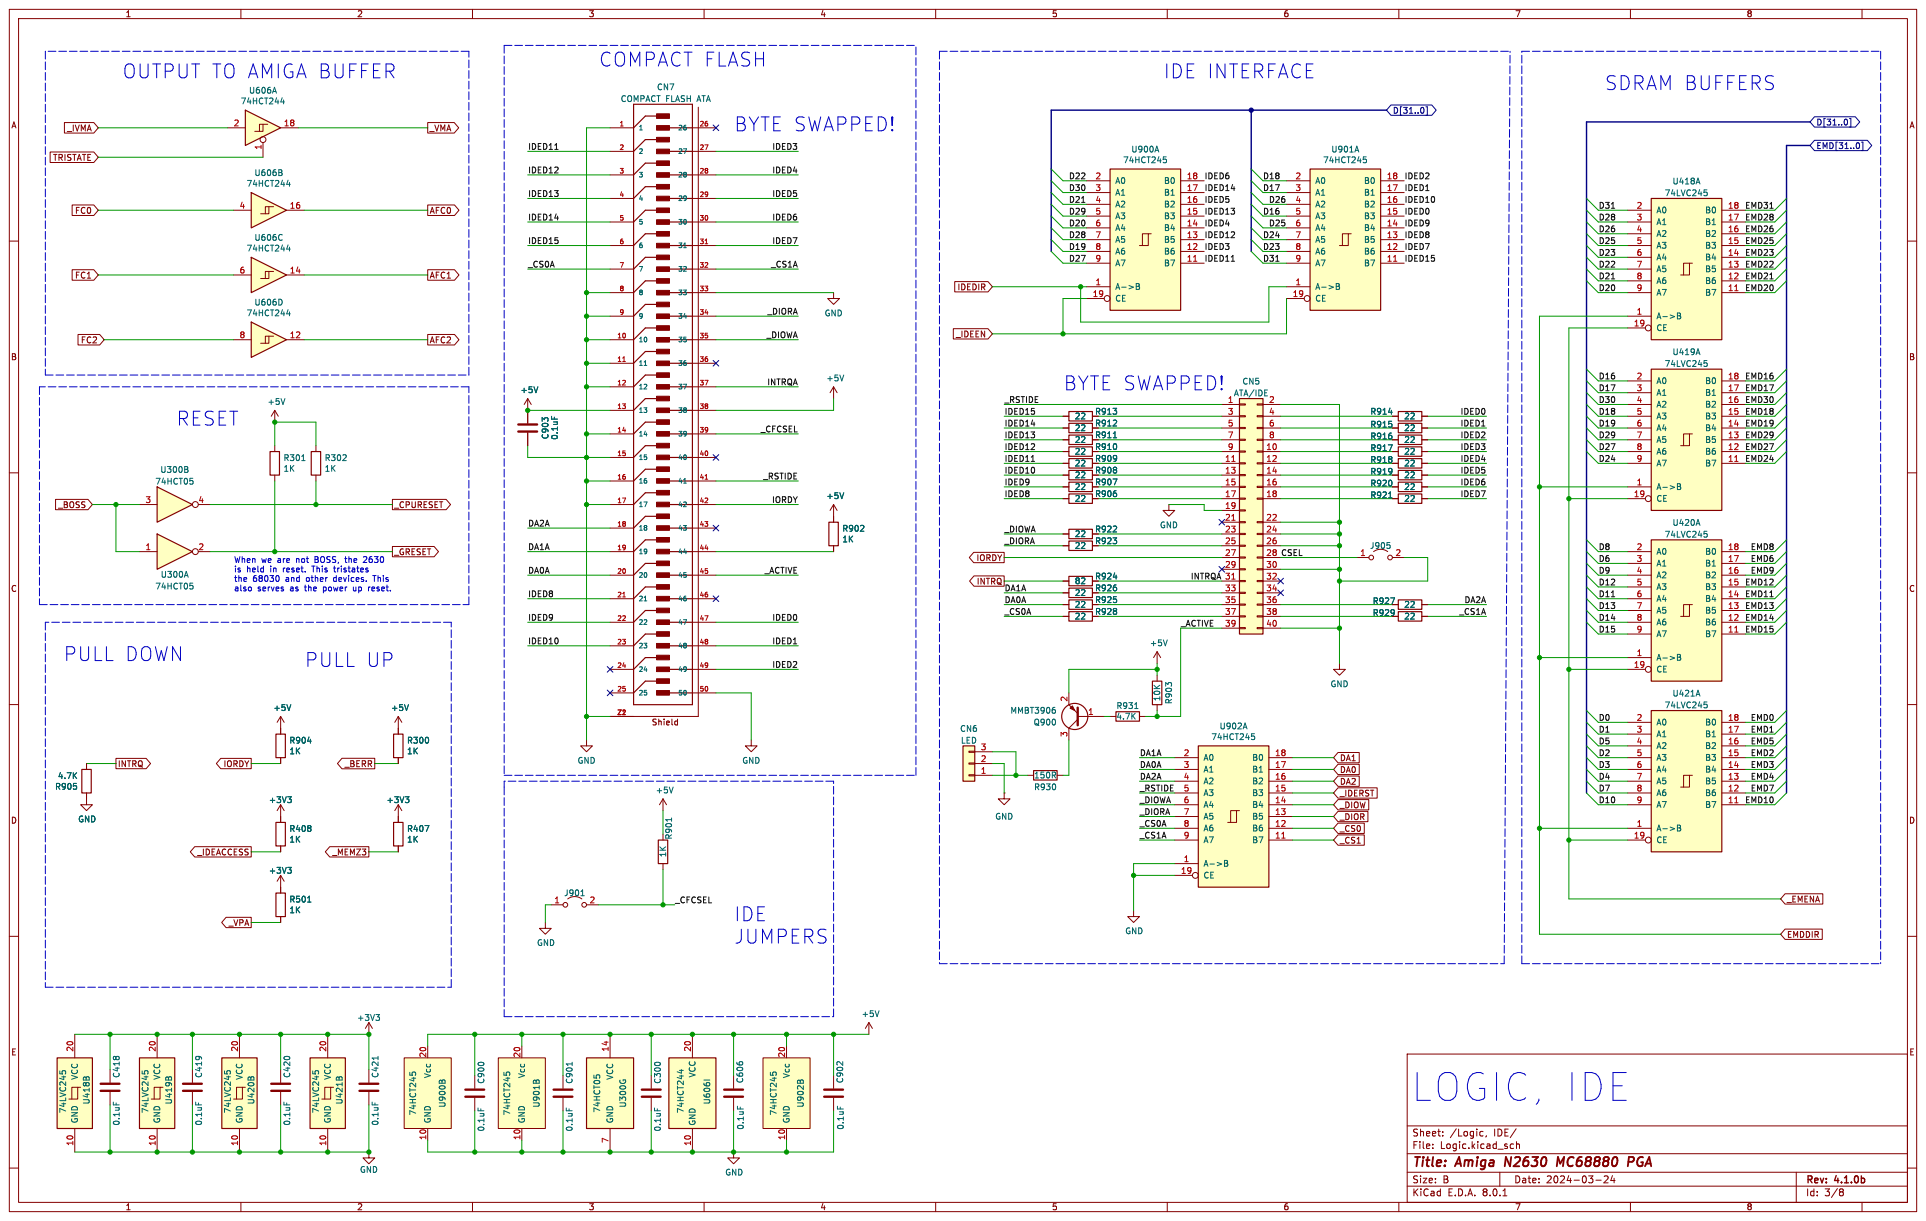
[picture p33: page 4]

OUTPUT TO AMIGA BUFFER

When we are not BOSS, the 2630
is held in reset. This tristates

Id: 3/8 Title: Amiga N2630 MC68880 PGA

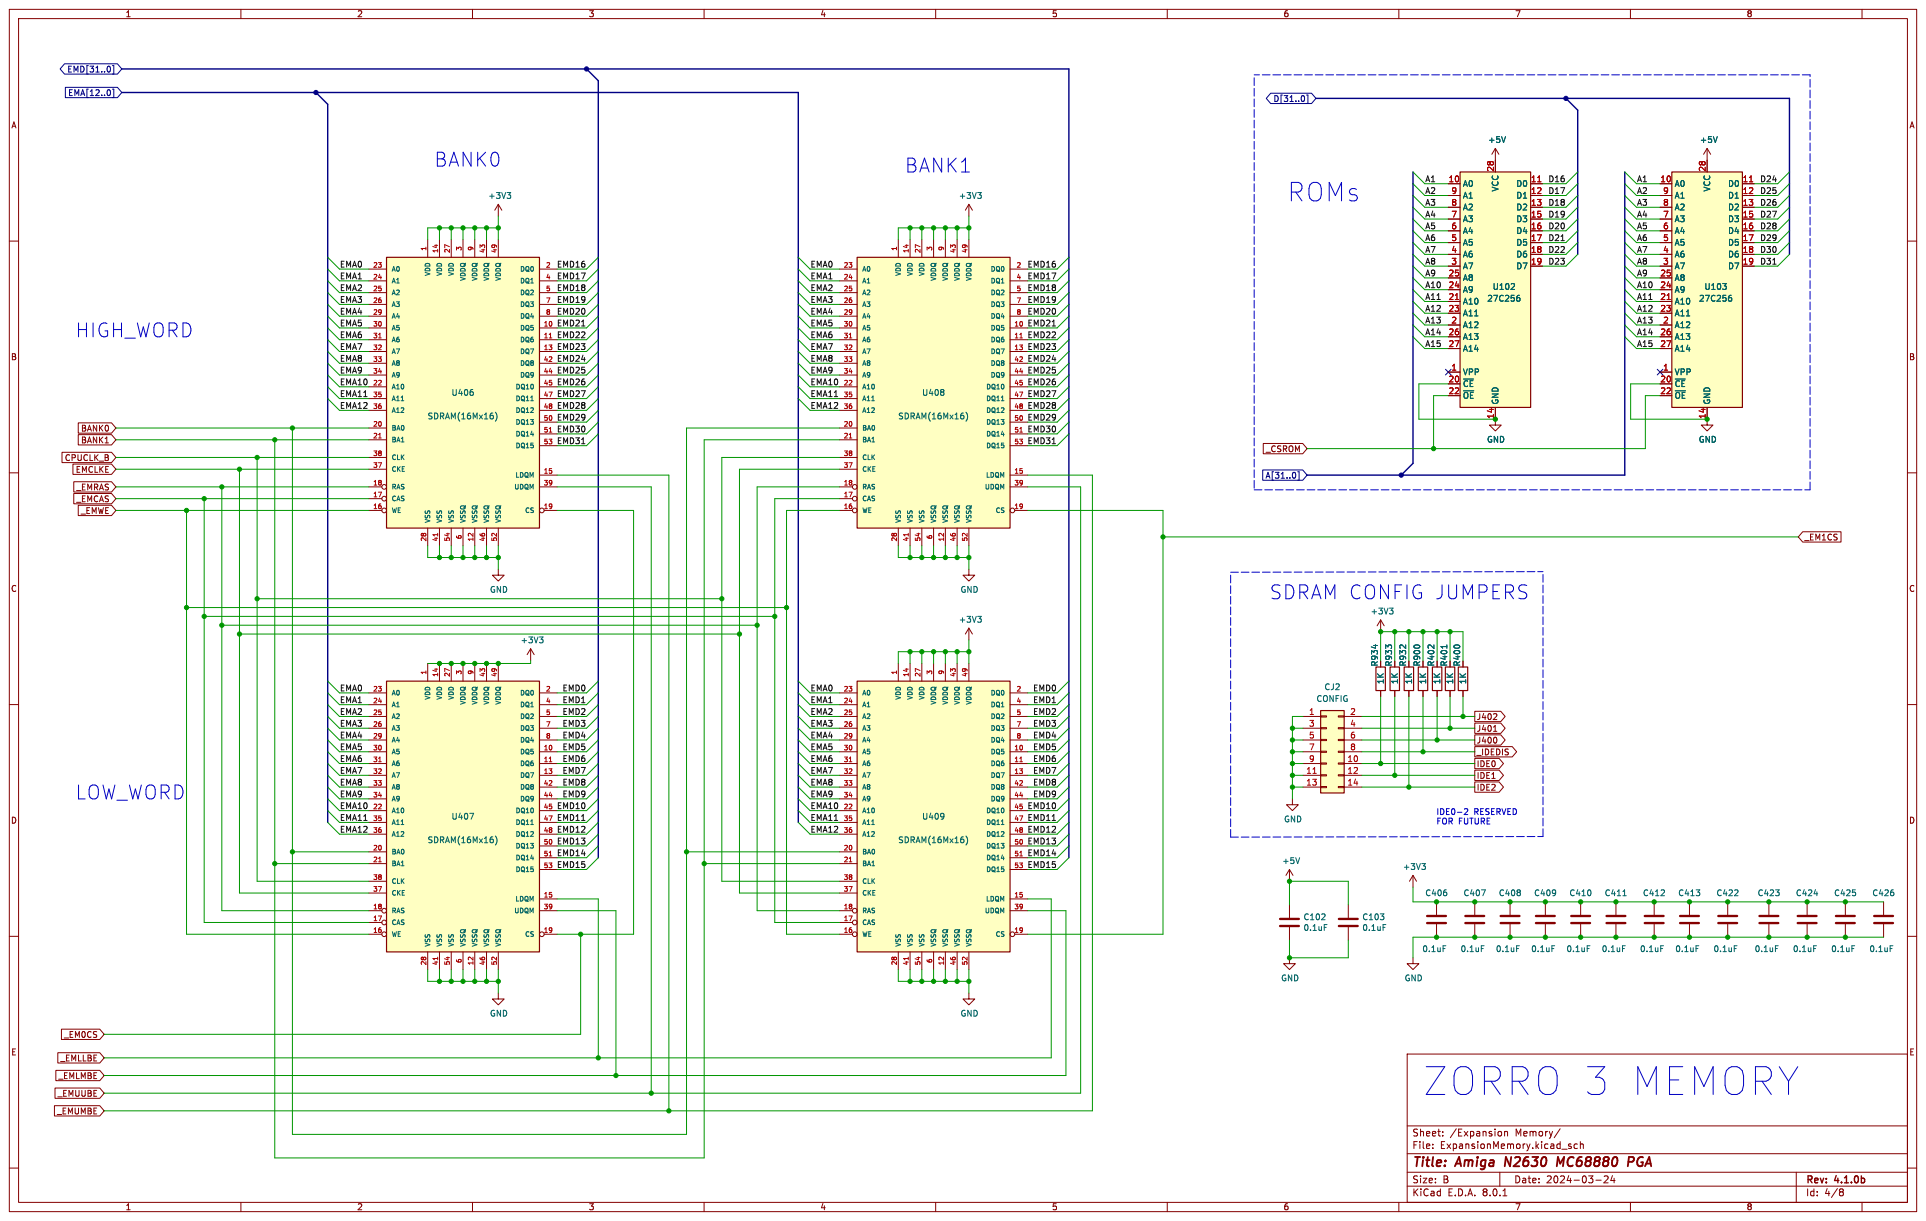
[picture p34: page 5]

Id: 4/8 Title: Amiga N2630 MC68880 PGA


Id: 5/8 Title: Amiga N2630 MC68880 PGA


Id: 6/8 Title: Amiga N2630 MC68880 PGA


Id: 8/8 Title: Amiga N2630 MC68880 PGA

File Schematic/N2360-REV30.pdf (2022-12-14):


Processor File: Processor.kicad_sch Expansion Memory

File: ExpansionMemory.kicad_sch
Base Memory, Spares, Power


NOTE: J401 and J402 have no effect if J400 is open.



OUTPUT TO AMIGA BUFFER

When we are not BOSS, the 2630
is held in reset. This tristates
the 68030 and other devices. This also serves as the power up reset.



J305 - Do not configure Z3 RAM Shorted/Autoconfigure Z3 RAM Open U700

J302 - A2000 Shorted/B2000 Open
J303 - Do not configure Z2 RAM Shorted/Autoconfigure Z2 RAM Open
J304 - AMIX Shorted/AmigaOS Open


Sheet: /Base Memory, Spares, Power/
File: BaseMemory.kicad_sch
Id: 6/8 Title: Amiga N2630


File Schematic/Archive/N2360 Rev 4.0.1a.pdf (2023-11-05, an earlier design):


Processor File: Processor.kicad_sch Expansion Memory File: ExpansionMemory.kicad_sch Card Edge File: Card Edge.kicad_sch Base Memory, Spares, Power File: BaseMemory.kicad_sch


File: jumpers.kicad_sch Sheet: /Jumpers/
Id: 1/8 Title: Amiga N2630



OUTPUT TO AMIGA BUFFER

When we are not BOSS, the 2630
is held in reset. This tristates




File: BaseMemory.kicad_sch Sheet: /Base Memory, Spares, Power/
Id: 6/8 Title: Amiga N2630


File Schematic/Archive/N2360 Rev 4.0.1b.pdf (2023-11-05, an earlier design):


Processor File: Processor.kicad_sch Expansion Memory File: ExpansionMemory.kicad_sch Card Edge File: Card Edge.kicad_sch Base Memory, Spares, Power File: BaseMemory.kicad_sch


File: jumpers.kicad_sch Sheet: /Jumpers/
Id: 1/8 Title: Amiga N2630


File: Processor.kicad_sch Sheet: /Processor/
Id: 2/8 Title: Amiga N2630


OUTPUT TO AMIGA BUFFER

When we are not BOSS, the 2630
is held in reset. This tristates




File: BaseMemory.kicad_sch Sheet: /Base Memory, Spares, Power/
Id: 6/8 Title: Amiga N2630


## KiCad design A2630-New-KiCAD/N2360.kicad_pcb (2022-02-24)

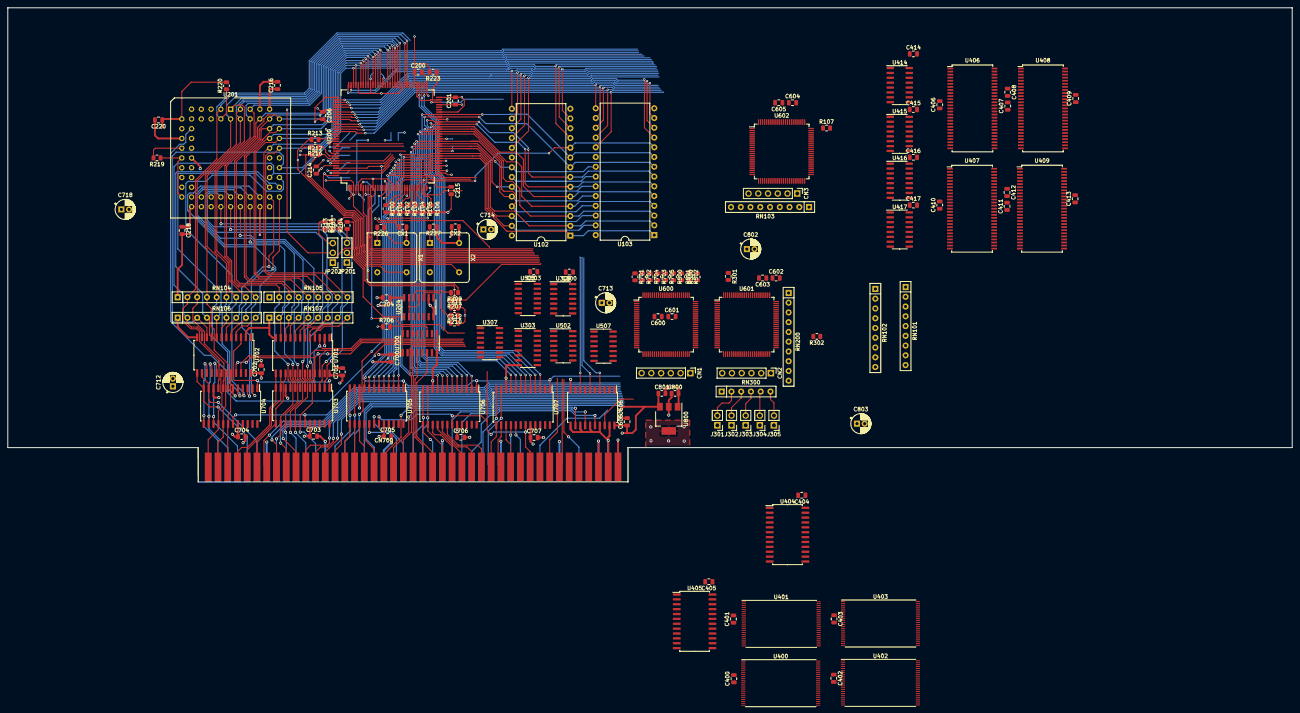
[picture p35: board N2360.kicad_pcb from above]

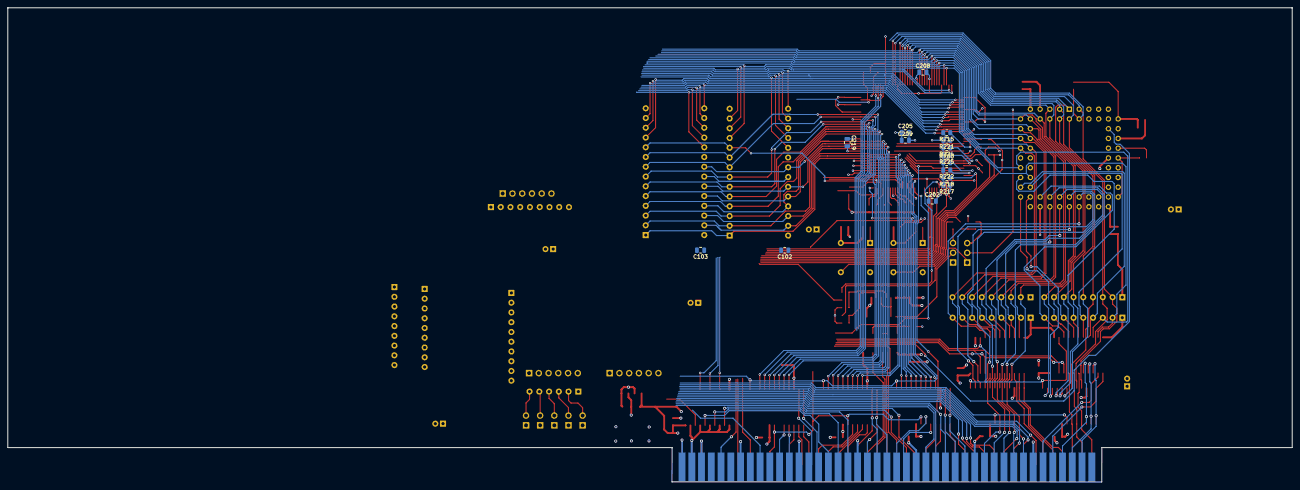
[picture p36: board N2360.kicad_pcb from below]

Board: 4 copper layers, 334.4 x 123.5 mm, 166 parts (15 on the bottom side), 297 nets.

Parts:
C102, C103, C204, C209, C404, C405, C700, C701, C702, C703, C704, C705, C706, C707: 0.22uF; C_0805_2012Metric
C200, C201, C202, C206, C208, C214, C215, C216, C218, C219, C220, C601, C603, C605: 0.1uF; C_0805_2012Metric
C205: 330pF; C_0805_2012Metric
C211, C212, C213: 22pF; C_0805_2012Metric
C300, C414, C415, C416, C417, C503, C606: 0.22; C_0805_2012Metric
C400, C401, C402, C403, C406, C407, C408, C409, C410, C411, C412, C413: 0.33uF; C_0805_2012Metric
C600, C602, C604: 0.01uF; C_0805_2012Metric
C712, C714, C718: 10uF; CP_Radial_D5.0mm_P2.00mm
C713, C802, C803: 47uF; CP_Radial_D5.0mm_P2.00mm
C800, C801: 10uF; R_0805_2012Metric
CN1: CPLD0; PinHeader_1x06_P2.54mm_Vertical
CN2, CN3: CPLD1; PinHeader_1x06_P2.54mm_Vertical
CN700: Amiga-2000-CPU-Slot; A2000_CPUSLOT_MALE
CX1, CX2: 0.01uF; C_0805_2012Metric
J301, J302, J303, J304, J305: Jumper_NO_Small; PinHeader_1x02_P2.54mm_Vertical
JP201: 25/28; PinHeader_1x03_P2.54mm_Vertical
JP202: 25/FPU; PinHeader_1x03_P2.54mm_Vertical
R100, R101, R102, R103, R104, R105, R106, R107, R217, R218, R219, R220, R221, R222, R223, R224, R225, R226, R227, R300, R500, R501, R502: 1K; R_0805_2012Metric
R203, R204, R207, R209, R210, R211: 68; R_0805_2012Metric
R212, R213, R215, R216, R701, R702, R703, R704, R705: 47; R_0805_2012Metric
R301: 470; R_0805_2012Metric
R302: 3.3K; R_0805_2012Metric
R700, R706: 1k; R_0805_2012Metric
RN101, RN102, RN103, RN104, RN105, RN106, RN107: 1K; R_Array_SIP9
RN200: 3.3K; R_Array_SIP10
RN300: 3.3K; R_Array_SIP6
U102, U103: 27C256; DIP-28_W15.24mm
U200: MC68030FE; PQFP-132_24x24mm_P0.635mm
U201: MC68882; PLCC-68_THT-Socket
U204, U307: 74HCT04; SOIC-14_3.9x8.7mm_P1.27mm
U300: 74HCT05; SOIC-14_3.9x8.7mm_P1.27mm
U303, U700: 74HCT174; SOIC-16_3.9x9.9mm_P1.27mm
U400, U401, U402, U403: CY7C1061G; TSOP-I-48_18.4x12mm_P0.5mm
U404, U405: CY74FCT821T; SOIC-24W_7.5x15.4mm_P1.27mm
U406, U407, U408, U409: SDRAM_512Mb(32Mx16); TSOP-II-54_22.2x10.16mm_P0.8mm
U414, U415, U416, U417: 74LVC257; SOIC-16_3.9x9.9mm_P1.27mm
U502, U503, U507: 74HCT74; SOIC-14_3.9x8.7mm_P1.27mm
U600, U601, U602: XC9572XL-TQ100; TQFP-100_14x14mm_P0.5mm
U606: 74HCT244; SOIC-20W_7.5x12.8mm_P1.27mm
U701, U702: 74FCT646; SOIC-24W_7.5x15.4mm_P1.27mm
U703, U704, U705, U706, U707: 74HCT245; SOIC-24W_7.5x15.4mm_P1.27mm
U800: LM1117-3.3; SOT-223
X1, X2: 25MHz; Oscillator_DIP-8

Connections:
7M: R702.2, U502.3 (C), U502.11 (C), U700.9 (Cp)
28M: CN700.9, JP201.1 (A)
+3V3: C400.1, C401.1, C402.2, C403.2, C406.1, C407.1, C408.1, C409.1, C410.1, C411.1, C412.1, C413.1, C414.1, C415.1, C416.1, C417.1, C600.1, C601.1, C602.1, C603.1, C604.1, C605.1, C800.1, C802.1, C803.1, CN1.6, CN2.6, CN3.6, RN300.1 (common), U400.12 (CE2), U400.37 (Vcc), U400.47 (_BYTE), U401.12 (CE2), U401.37 (Vcc), U401.47 (_BYTE), U402.12 (CE2), U402.37 (Vcc), U402.47 (_BYTE), U403.12 (CE2), U403.37 (Vcc), U403.47 (_BYTE), U406.1 (VDD), U406.3 (VDDQ), U406.9 (VDDQ), U406.14 (VDD), U406.27 (VDD), U406.43 (VDDQ), U406.49 (VDDQ), U407.1 (VDD), U407.3 (VDDQ), U407.9 (VDDQ), U407.14 (VDD), U407.27 (VDD), U407.43 (VDDQ), U407.49 (VDDQ), U408.1 (VDD), U408.3 (VDDQ), U408.9 (VDDQ), U408.14 (VDD), U408.27 (VDD), U408.43 (VDDQ), U408.49 (VDDQ), U409.1 (VDD), U409.3 (VDDQ), U409.9 (VDDQ), U409.14 (VDD), U409.27 (VDD), U409.43 (VDDQ), U409.49 (VDDQ), U414.16 (VCC), U415.16 (VCC), U416.16 (VCC), U417.16 (VCC), U600.5 (VCC), U600.26 (VCCIO), U600.38 (VCCIO), U600.51 (VCCIO), U600.57 (VCC), U600.88 (VCCIO), U600.98 (VCC), U601.5 (VCC), U601.26 (VCCIO), U601.38 (VCCIO), U601.51 (VCCIO), U601.57 (VCC), U601.88 (VCCIO), U601.98 (VCC), U602.5 (VCC), U602.26 (VCCIO), U602.38 (VCCIO), U602.51 (VCCIO), U602.57 (VCC), U602.88 (VCCIO), U602.98 (VCC), U800.2 (VO), U800.4 (VO)
+5V: C102.1, C103.1, C200.1, C201.1, C202.1, C204.1, C205.1, C206.1, C208.1, C209.1, C214.1, C215.1, C216.1, C218.1, C219.1, C220.1, C300.1, C404.1, C405.1, C503.1, C606.1, C701.1, C702.1, C703.1, C704.1, C705.1, C706.1, C707.1, C712.1, C713.1, C714.1, C718.1, C801.1, CN700.5, CN700.6, CX1.1, CX2.1, R217.2, R218.2, R219.2, R220.2, R221.2, R222.2, R223.2, R224.2, R225.2, R226.1, R227.1, R301.1, R302.1, R500.1, R501.1, R502.1, R700.1, R706.1, RN200.1 (common), U102.28 (VCC), U103.28 (VCC), U200.4 (VCC), U200.8 (VCC), U200.18 (VCC), U200.30 (VCC), U200.49 (VCC), U200.63 (VCC), U200.72 (VCC), U200.85 (VCC), U200.105 (VCC), U200.115 (VCC), U200.116 (VCC), U200.128 (VCC), U201.10 (VCC), U201.16 (VCC), U201.17 (VCC), U201.27 (VCC), U201.43 (VCC), U201.52 (VCC), U201.53 (VCC), U201.61 (VCC), U204.14 (VCC), U300.14 (VCC), U303.11 (D3), U303.16 (VCC), U404.24 (Vcc), U405.24 (Vcc), U502.13 (~R), U503.1 (~R), U503.13 (~R), U503.14 (VCC), U507.4 (~S), U606.20 (VCC), U701.24 (Vcc), U702.24 (Vcc), U703.20 (Vcc), U704.20 (Vcc), U705.20 (Vcc), U706.20 (Vcc), U707.20 (Vcc), U800.3 (VI), X1.8 (Vcc), X2.8 (Vcc)
/Base Memory/MA0: U400.25 (A0), U401.25 (A0), U402.25 (A0), U403.25 (A0), U404.23 (Y0)
/Base Memory/MA1: U400.24 (A1), U401.24 (A1), U402.24 (A1), U403.24 (A1), U404.22 (Y1)
/Base Memory/MA2: U400.23 (A2), U401.23 (A2), U402.23 (A2), U403.23 (A2), U404.21 (Y2)
/Base Memory/MA3: U400.22 (A3), U401.22 (A3), U402.22 (A3), U403.22 (A3), U404.20 (Y3)
/Base Memory/MA4: U400.21 (A4), U401.21 (A4), U402.21 (A4), U403.21 (A4), U404.19 (Y4)
/Base Memory/MA5: U400.20 (A5), U401.20 (A5), U402.20 (A5), U403.20 (A5), U404.18 (Y5)
/Base Memory/MA6: U400.19 (A6), U401.19 (A6), U402.19 (A6), U403.19 (A6), U404.17 (Y6)
/Base Memory/MA7: U400.18 (A7), U401.18 (A7), U402.18 (A7), U403.18 (A7), U404.16 (Y7)
/Base Memory/MA8: U400.8 (A8), U401.8 (A8), U402.8 (A8), U403.8 (A8), U404.15 (Y8)
/Base Memory/MA9: U400.7 (A9), U401.7 (A9), U402.7 (A9), U403.7 (A9), U404.14 (Y9)
/Base Memory/MA10: U400.6 (A10), U401.6 (A10), U402.6 (A10), U403.6 (A10), U405.23 (Y0)
/Base Memory/MA11: U400.5 (A11), U401.5 (A11), U402.5 (A11), U403.5 (A11), U405.22 (Y1)
/Base Memory/MA12: U400.4 (A12), U401.4 (A12), U402.4 (A12), U403.4 (A12), U405.21 (Y2)
/Base Memory/MA13: U400.3 (A13), U401.3 (A13), U402.3 (A13), U403.3 (A13), U405.20 (Y3)
/Base Memory/MA14: U400.2 (A14), U401.2 (A14), U402.2 (A14), U403.2 (A14), U405.19 (Y4)
/Base Memory/MA15: U400.1 (A15), U401.1 (A15), U402.1 (A15), U403.1 (A15), U405.18 (Y5)
/Base Memory/MA16: U400.48 (A16), U401.48 (A16), U402.48 (A16), U403.48 (A16), U405.17 (Y6)
/Base Memory/MA17: U400.17 (A17), U401.17 (A17), U402.17 (A17), U403.17 (A17), U405.16 (Y7)
/Base Memory/MA18: U400.16 (A18), U401.16 (A18), U402.16 (A18), U403.16 (A18), U405.15 (Y8)
/Base Memory/MA19: U400.9 (A19), U401.9 (A19), U402.9 (A19), U403.9 (A19), U405.14 (Y9)
/CPLD 1/TCK0: CN1.3, U600.48 (TCK)
/CPLD 1/TCK1: CN2.3, CN3.3, U601.48 (TCK), U602.48 (TCK)
/CPLD 1/TDI0: CN1.1, U600.45 (TDI)
/CPLD 1/TDI1: CN2.1, CN3.1, U601.45 (TDI), U602.45 (TDI)
/CPLD 1/TDO0: CN1.4, U600.83 (TDO)
/CPLD 1/TDO1: CN2.4, CN3.4, U601.83 (TDO), U602.83 (TDO)
/CPLD 1/TMS0: CN1.2, U600.47 (TMS)
/CPLD 1/TMS1: CN2.2, CN3.2, U601.47 (TMS), U602.47 (TMS)
/Card Edge/AA1: CN700.29, U707.12 (B6)
/Card Edge/AA2: CN700.27, U707.11 (B7)
/Card Edge/AA3: CN700.26, U707.14 (B4)
/Card Edge/AA4: CN700.24, U707.15 (B3)
/Card Edge/AA5: CN700.21, U707.17 (B1)
/Card Edge/AA6: CN700.23, U707.16 (B2)
/Card Edge/AA7: CN700.28, U707.13 (B5)
/Card Edge/AA8: CN700.30, U706.18 (B0)
/Card Edge/AA9: CN700.32, U706.17 (B1)
/Card Edge/AA10: CN700.34, U706.16 (B2)
/Card Edge/AA11: CN700.36, U706.15 (B3)
/Card Edge/AA12: CN700.38, U706.14 (B4)
/Card Edge/AA13: CN700.39, U706.13 (B5)
/Card Edge/AA14: CN700.41, U706.11 (B7)
/Card Edge/AA15: CN700.43, U706.12 (B6)
/Card Edge/AA16: CN700.45, U705.18 (B0)
/Card Edge/AA17: CN700.47, U705.17 (B1)
/Card Edge/AA18: CN700.52, U705.16 (B2)
/Card Edge/AA19: CN700.54, U705.15 (B3)
/Card Edge/AA20: CN700.56, U705.14 (B4)
/Card Edge/AA21: CN700.58, U705.13 (B5)
/Card Edge/AA22: CN700.57, U705.11 (B7)
/Card Edge/AA23: CN700.59, U705.12 (B6)
/Card Edge/AD0: CN700.75, U702.14 (B7), U704.11 (B7)
/Card Edge/AD1: CN700.77, U702.13 (B8), U704.12 (B6)
/Card Edge/AD2: CN700.79, U702.17 (B4), U704.15 (B3)
/Card Edge/AD3: CN700.81, U702.16 (B5), U704.14 (B4)
/Card Edge/AD4: CN700.83, U702.15 (B6), U704.13 (B5)
/Card Edge/AD5: CN700.86, U702.18 (B3), U704.16 (B2)
/Card Edge/AD6: CN700.84, U702.19 (B2), U704.17 (B1)
/Card Edge/AD7: CN700.82, U702.20 (B1), U704.18 (B0)
/Card Edge/AD8: CN700.80, U701.13 (B8), U703.12 (B6)
/Card Edge/AD9: CN700.78, U701.14 (B7), U703.11 (B7)
/Card Edge/AD10: CN700.76, U701.15 (B6), U703.13 (B5)
/Card Edge/AD11: CN700.71, U701.16 (B5), U703.14 (B4)
/Card Edge/AD12: CN700.69, U701.17 (B4), U703.15 (B3)
/Card Edge/AD13: CN700.67, U701.18 (B3), U703.16 (B2)
/Card Edge/AD14: CN700.65, U701.19 (B2), U703.17 (B1)
/Card Edge/AD15: CN700.63, U701.20 (B1), U703.18 (B0)
A0: RN103.9 (R8), U200.21 (A0), U601.32, U602.32
A1: RN103.8 (R7), U102.10 (A0), U103.10 (A0), U200.22 (A1), U201.25 (A1), U600.59, U601.35, U602.35, U707.8 (A6)
A2: RN103.7 (R6), U102.9 (A1), U103.9 (A1), U200.59 (A2), U201.24 (A2), U404.2 (D0), U414.2 (I0a), U601.37, U602.37, U707.9 (A7)
A3: RN103.6 (R5), U102.8 (A2), U103.8 (A2), U200.58 (A3), U201.23 (A3), U404.3 (D1), U414.5 (I0b), U601.41, U602.41, U707.6 (A4)
A4: RN103.5 (R4), U102.7 (A3), U103.7 (A3), U200.56 (A4), U201.22 (A4), U404.4 (D2), U414.14 (I0c), U601.42, U602.42, U707.5 (A3)
A5: RN103.4 (R3), U102.6 (A4), U103.6 (A4), U200.55 (A5), U404.5 (D3), U414.11 (I0d), U601.49, U602.49, U707.3 (A1)
A6: RN103.3 (R2), U102.5 (A5), U103.5 (A5), U200.54 (A6), U404.6 (D4), U415.2 (I0a), U601.50, U602.50, U707.4 (A2)
A7: RN103.2 (R1), U102.4 (A6), U103.4 (A6), U200.53 (A7), U404.7 (D5), U415.5 (I0b), U707.7 (A5)
A8: RN102.9 (R8), U102.3 (A7), U103.3 (A7), U200.52 (A8), U404.8 (D6), U415.14 (I0c), U602.52, U706.2 (A0)
A9: RN102.8 (R7), U102.25 (A8), U103.25 (A8), U200.51 (A9), U404.9 (D7), U415.11 (I0d), U706.3 (A1)
A10: RN102.7 (R6), U102.24 (A9), U103.24 (A9), U200.48 (A10), U404.10 (D8), U416.2 (I0a), U706.4 (A2)
A11: RN102.6 (R5), U102.21 (A10), U103.21 (A10), U200.47 (A11), U404.11 (D9), U416.5 (I0b), U706.5 (A3)
A12: RN102.5 (R4), U102.23 (A11), U103.23 (A11), U200.46 (A12), U405.2 (D0), U416.14 (I0c), U706.6 (A4)
A13: RN102.4 (R3), U102.2 (A12), U103.2 (A12), U200.45 (A13), U405.3 (D1), U416.11 (I0d), U601.52, U706.7 (A5)
A14: RN102.2 (R1), U102.26 (A13), U103.26 (A13), U200.43 (A14), U405.4 (D2), U417.2 (I0a), U601.53, U706.9 (A7)
A15: RN102.3 (R2), U102.27 (A14), U103.27 (A14), U200.42 (A15), U405.5 (D3), U414.3 (I1a), U601.54, U706.8 (A6)
A16: RN101.9 (R8), U102.1 (VPP), U103.1 (VPP), U200.41 (A16), U405.6 (D4), U414.6 (I1b), U601.55, U705.2 (A0)
A17: RN101.8 (R7), U200.40 (A17), U405.7 (D5), U414.13 (I1c), U601.56, U705.3 (A1)
A18: RN101.7 (R6), U200.39 (A18), U405.8 (D6), U414.10 (I1d), U601.58, U705.4 (A2)
A19: RN101.6 (R5), U200.38 (A19), U405.9 (D7), U415.3 (I1a), U601.59, U705.5 (A3)
A20: RN101.5 (R4), U200.37 (A20), U405.10 (D8), U415.6 (I1b), U601.60, U705.6 (A4)
A21: RN101.4 (R3), U200.36 (A21), U405.11 (D9), U415.13 (I1c), U601.61, U705.7 (A5)
A22: RN101.2 (R1), U200.34 (A22), U415.10 (I1d), U601.63, U602.53, U705.9 (A7)
A23: RN101.3 (R2), U200.33 (A23), U416.3 (I1a), U601.64, U602.54, U705.8 (A6)
A24: R107.1, U200.32 (A24), U416.6 (I1b), U602.55
A25: R106.1, U200.31 (A25), U602.56
A26: R105.1, U200.29 (A26), U602.58
A27: R104.1, U200.28 (A27)
A28: R103.1, U200.27 (A28)
A29: R102.1, U200.26 (A29)
A30: R101.1, U200.24 (A30)
A31: R100.1, U200.23 (A31)
ADDIR: U600.37, U701.3 (DIR), U702.3 (DIR), U703.1 (A->B), U704.1 (A->B)
AFC0: CN700.31, U606.16
AFC1: CN700.33, U606.14
AFC2: CN700.35, U606.12
AR_W: CN700.68, U600.14, U601.79
AS: U404.13 (CP), U405.13 (CP), U600.68
B2000: J302.2, RN300.3 (R2), U600.82
BGDIS: U502.4 (~S), U502.10 (~S)
CONFIGED: U600.33, U601.30
CPUCLK_A: R207.1, U406.38 (CLK), U407.38 (CLK), U408.38 (CLK), U409.38 (CLK), U600.91, U601.87, U602.12
D0: RN104.2 (R1), U200.75 (D0), U201.3 (D0), U401.29 (O0), U403.29 (O0), U406.2 (DQ0), U408.2 (DQ0), U704.9 (A7)
D1: RN104.3 (R2), U200.76 (D1), U201.2 (D1), U401.31 (O1), U403.31 (O1), U406.4 (DQ1), U408.4 (DQ1), U704.8 (A6)
D2: RN104.6 (R5), U200.78 (D2), U201.1 (D2), U401.33 (O2), U403.33 (O2), U406.5 (DQ2), U408.5 (DQ2), U704.5 (A3)
D3: RN104.5 (R4), U200.79 (D3), U201.68 (D3), U401.35 (O3), U403.35 (O3), U406.7 (DQ3), U408.7 (DQ3), U704.6 (A4)
D4: RN104.4 (R3), U200.80 (D4), U201.67 (D4), U401.38 (O4), U403.38 (O4), U406.8 (DQ4), U408.8 (DQ4), U704.7 (A5)
D5: RN104.7 (R6), U200.81 (D5), U201.66 (D5), U401.40 (O5), U403.40 (O5), U406.10 (DQ5), U408.10 (DQ5), U704.4 (A2)
D6: RN104.8 (R7), U200.82 (D6), U201.65 (D6), U401.42 (O6), U403.42 (O6), U406.11 (DQ6), U408.11 (DQ6), U704.3 (A1)
D7: RN104.9 (R8), U200.83 (D7), U201.64 (D7), U401.44 (O7), U403.44 (O7), U406.13 (DQ7), U408.13 (DQ7), U704.2 (A0)
D8: RN105.3 (R2), U200.86 (D8), U201.62 (D8), U401.30 (O8), U403.30 (O8), U406.42 (DQ8), U408.42 (DQ8), U703.8 (A6)
D9: RN105.2 (R1), U200.87 (D9), U201.60 (D9), U401.32 (O9), U403.32 (O9), U406.44 (DQ9), U408.44 (DQ9), U703.9 (A7)
D10: RN105.4 (R3), U200.88 (D10), U201.59 (D10), U401.34 (O10), U403.34 (O10), U406.45 (DQ10), U408.45 (DQ10), U703.7 (A5)
D11: RN105.5 (R4), U200.89 (D11), U201.58 (D11), U401.36 (O11), U403.36 (O11), U406.47 (DQ11), U408.47 (DQ11), U703.6 (A4)
D12: RN105.6 (R5), U200.91 (D12), U201.57 (D12), U401.39 (O12), U403.39 (O12), U406.48 (DQ12), U408.48 (DQ12), U703.5 (A3)
D13: RN105.7 (R6), U200.92 (D13), U201.56 (D13), U401.41 (O13), U403.41 (O13), U406.50 (DQ13), U408.50 (DQ13), U703.4 (A2)
D14: RN105.8 (R7), U200.93 (D14), U201.55 (D14), U401.43 (014), U403.43 (014), U406.51 (DQ14), U408.51 (DQ14), U703.3 (A1)
D15: RN105.9 (R8), U200.94 (D15), U201.54 (D15), U401.45 (O15), U403.45 (O15), U406.53 (DQ15), U408.53 (DQ15), U703.2 (A0)
D16: RN106.3 (R2), U102.11 (D0), U200.96 (D16), U201.50 (D16), U303.3 (D0), U400.29 (O0), U402.29 (O0), U407.2 (DQ0), U409.2 (DQ0), U702.10 (A7)
D17: RN106.2 (R1), U102.12 (D1), U200.97 (D17), U201.49 (D17), U303.4 (D1), U400.31 (O1), U402.31 (O1), U407.4 (DQ1), U409.4 (DQ1), U702.11 (A8)
D18: RN106.6 (R5), U102.13 (D2), U200.98 (D18), U201.48 (D18), U303.6 (D2), U400.33 (O2), U402.33 (O2), U407.5 (DQ2), U409.5 (DQ2), U702.7 (A4)
D19: RN106.5 (R4), U102.15 (D3), U200.99 (D19), U201.47 (D19), U303.13 (D4), U400.35 (O3), U402.35 (O3), U407.7 (DQ3), U409.7 (DQ3), U702.8 (A5)
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

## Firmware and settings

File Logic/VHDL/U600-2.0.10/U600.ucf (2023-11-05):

NET "nBOSS"			LOC = "P1" ;
//NET "nDS"			LOC = "P2" ;
NET "nSTERM"		LOC = "P4" ;
NET "nBG"			LOC = "P6" ;
//NET "CDAC"			LOC = "P7" ;
NET "IPLCLK"		LOC = "P8" ;
NET "DRSEL"			LOC = "P9" ;
NET "nADOEH"		LOC = "P10" ;
NET "nC1"			LOC = "P11" ;	
NET "nC3"			LOC = "P12" ;
NET "nADOEL"		LOC = "P13" ;

NET "CPUCLK"		LOC = "P15" ;
NET "CPUCLK"		BUFG = CLK ;

NET "nAAS"			LOC = "P16" ; 
NET "nVMA"			LOC = "P17" ;
NET "ARnW"			LOC = "P18" ;
NET "nDTACK"		LOC = "P19" ;
NET "nABG"			LOC = "P20" ;
NET "nABGACK"		LOC = "P22" ;
NET "nABR"			LOC = "P23" ;
NET "nRESET"		LOC = "P24" ;
NET "E"				LOC = "P25" ;
NET "nVPA"			LOC = "P27" ;
NET "ADDIR"			LOC = "P31" ;
NET "A7M"			LOC = "P32" ; 

NET "B2000"			LOC = "P33" ;
NET "nBGACK"		LOC = "P34" ;
NET "nLDS"			LOC = "P35" ;
NET "nUDS"			LOC = "P36" ;
NET "TRISTATE"		LOC = "P38" ;
NET "nMEMZ2"		LOC = "P39" ;
NET "CLK7"			LOC = "P40" ;
NET "nCLK7"			LOC = "P42" ;
NET "SMDIS"			LOC = "P43" ;
//NET "nIDEACCESS"		LOC = "P45" ;
NET "nAS"			LOC = "P46" ;
NET "RnW"			LOC = "P47" ;
NET "FC<2>"			LOC = "P48" ;	
NET "FC<0>"			LOC = "P50" ;
NET "nDSACK1"		LOC = "P51" ;
NET "nBR"			LOC = "P52" ;
NET "A<0>"			LOC = "P56" ;
NET "A<1>"			LOC = "P57" ;
NET "nHALT"			LOC = "P58" ;
//NET "nCPURESET"	LOC = "P59" ;
NET "FC<1>"			LOC = "P60" ;
NET "MODE68K"		LOC = "P61" ;
NET "SIZ<1>"		LOC = "P62" ;
NET "SIZ<0>"		LOC = "P63" ;
NET "nBERR"			LOC = "P64" ;

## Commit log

2022-01-11 Hex and Binary Values for AUTOCONFIG Offsets
    Taken from the Amiga Developer's Reference Guide.
    [Autoconfig-Offsets.xlsx]
2022-01-11 AUTOCONFIG Offsets
    Taken from the Amiga Developer's Guide.
    [Autoconfig-Offsets.csv]
2022-04-16 Update SDRAM Refresh Timing.csv
    [SDRAM Refresh Timing.csv]
2022-07-23 Rev 2.1 Gerber
2022-09-10 Uploaded Rev 2.3 PGA Schematic
2022-09-10 Rev 2.3 PGA Final
    [jumpers.kicad_sch]
2022-09-28 Fixed 68k SM Crash
    [U600.ucf]
2022-10-18 Add DMA Timing Diagrams
2022-10-20 Final DMA Timing Diagrams
2022-11-07 Fixed config chain bug.
2022-11-26 Replaced by Rev 3.0
    [100SP1T1B1M7QE--3DModel-STEP-520916.STEP, BaseMemory.kicad_sch, COMPACT-FLASH-SLOT.step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]
2023-01-22 Add PCB info.
2023-01-23 Interactive BOM
2023-01-23 Exclude non-BOM items.
    [BaseMemory.kicad_sch, Card Edge.kicad_sch, ExpansionMemory.kicad_sch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]
2023-01-24 Fixed 74AHCT04 part number.
    [N2360-REV30-BOM.csv]
2023-02-05 Add copper pours to top and bottom layers.
    [100SP1T1B1M7QE--3DModel-STEP-520916.STEP, BaseMemory.kicad_sch, COMPACT-FLASH-SLOT.step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]
2023-02-14 DMA Fix
2023-02-19 Added EPROM speed.
    [N2630-REV30-BOM.csv]
2023-02-20 Added A2000 bracket.
    [N2630-A2000-Bracket-Body.stl, N2630-A2000-Bracket.FCStd]
2023-02-20 A2000 bracket.
2023-04-03 Add EATX Bracket
    [A26x0 Slot Cover.FCStd, N2630-Slot-Cover.stl]
2023-11-05 Cleanup Files
    [100SP1T1B1M7QE--3DModel-STEP-520916.STEP, BaseMemory.kicad_sch, COMPACT-FLASH-SLOT.step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]
2023-11-05 Push Rev 4.0.1 KiCAD and Gerber.
    [100SP1T1B1M7QE--3DModel-STEP-520916.STEP, BaseMemory.kicad_sch, COMPACT-FLASH-SLOT.step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]
2023-11-05 Push Rev 4.0.1a/b schematics.
2023-11-05 Push Rev 4.0.1a/b IBOM
    [BaseMemory.kicad_sch, Card Edge.kicad_sch, ExpansionMemory.kicad_sch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]
2023-12-27 Fix missing component values on gerber silkscreen. 26-DEC-2023
2024-03-27 Revision 4.1.0
    [BaseMemory.kicad_sch, Card Edge.kicad_sch, ExpansionMemory.kicad_sch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]
2024-03-27 Rename KiCAD Folders
    [100SP1T1B1M7QE--3DModel-STEP-520916.STEP, BaseMemory.kicad_sch, COMPACT-FLASH-SLOT.step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]
2024-03-27 Add Rev 4.0.1x to Archive
    [100SP1T1B1M7QE--3DModel-STEP-520916.STEP, BaseMemory.kicad_sch, COMPACT-FLASH-SLOT.step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]
